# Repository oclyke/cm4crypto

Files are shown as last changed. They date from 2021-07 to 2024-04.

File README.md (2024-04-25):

# cm4crypto

cm4crypto is an adapter board that allows you to use an M-Key M.2 compatible module with the Raspberry Pi Compute Module 4 (cm4).

adding fast terabyte SSD options within a sleek RPi 4 format makes the cm4crypto perfect for uses like:
* participating in blockchain networks
* acting as a home media server
* hosting a local database

## status

this project is no longer actively developed.
the source material will continue to be available for reference.

additional resources:

* [onshape model](https://cad.onshape.com/documents/3095ac02ee5d7dd8a1b9e12a/w/86bdcc88d4120b9515956abd/e/6d8a025f4a8b2a44825a6443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)
* [time lapse of routing the board](https://youtu.be/ZWktmO8pLDk)

## features

* Adds M.2 M-Key PCIe x1 interface for use with NVMe SSDs or other compatible modules
* Designed for use in the [Flirc RPi 4 case](https://flirc.tv/more/raspberry-pi-4-case)
* Power Over Ethernet (PoE) support
* Camera Interface

# M.2 compatibility

M.2 specifies a connector layout, standard interfaces, and a few form factors. with such a wide variety of options available no single product can hope to support them all. here are the things you should check to see if your desired module is compatible:

property | value | notes
--- | ------- | ------
key | **M** | the M.2 connector on the cm4crypto uses an **M key**
interface | **PCIe x1** | though the M key standard supports PCIe x4 the cm4 only has x1 PCIe lane available. thanks to PCIe compatibility this should only reduce performance, not prevent functionality
dimensions | up to **22 x 80** mm | to fit in the case 

## RPi 4 compatibility

the cm4rypto inherently gains some compatibility with RPi 4 accessories since it was designed to work with the sleek Flirc case however design tradeoffs had to be made as well. 

### compatible

* 1x Gigabit ethernet
* 2x micro HDMI ports
* 1x USB-C port for power or USB OTG
* 1x USB-A port (USB 2.0)

### discrepancies

* there is **no 3.5mm audio jack**
* **GPIO is very limited** - only GPIO 2, 3, and 14 are available along with the first set of power pins (for PoE compatibility)
* the **camera interface is relocated** so that it comes out near the sd card
* the **sd card receptacle is slightly offset** to allow for the M.2 connector

## compatible / recommended products

### cases
* [Flirc Raspberry Pi 4 Case](https://flirc.tv/more/raspberry-pi-4-case)

### PoE hats
* [CMC Tech 3.5A](https://cctvfactory.com/copy-of-cmc-tech-5-2v-3-5a-17-5watt-power-over-ethernet-poe-hat-for-raspberry-pi-4-model-b-and-pi-3-model-b-ieee-802-3af-or-802-3at-poe-netwo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) (available on Amazon)
* 

# show and tell

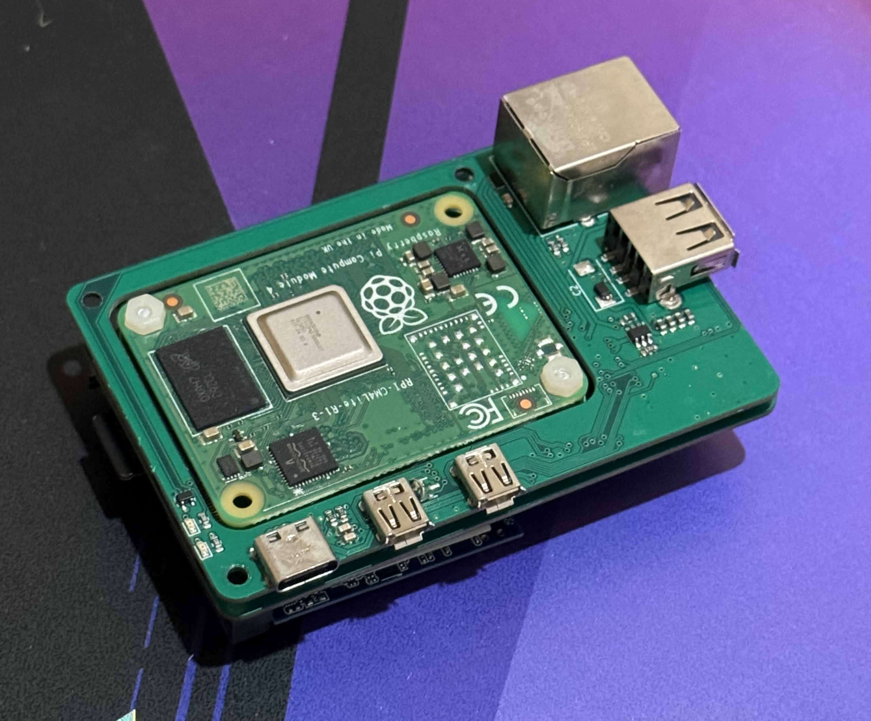
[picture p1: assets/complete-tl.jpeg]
cm4crypto


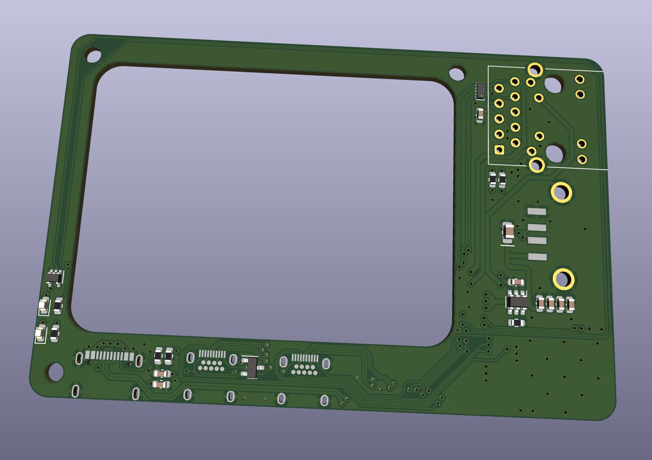
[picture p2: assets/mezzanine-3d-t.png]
mezzanine 3d top

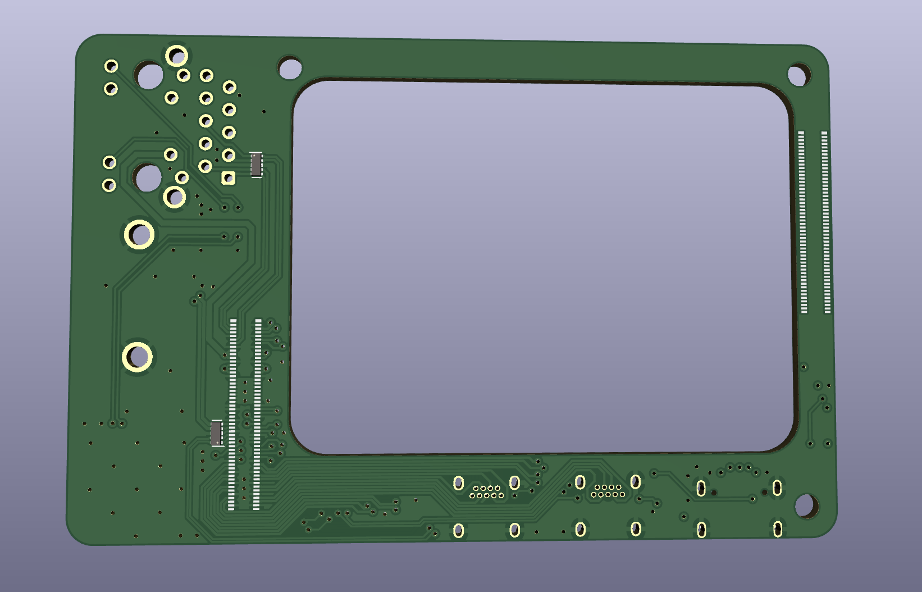
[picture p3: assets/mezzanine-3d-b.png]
mezzanine 3d bottom

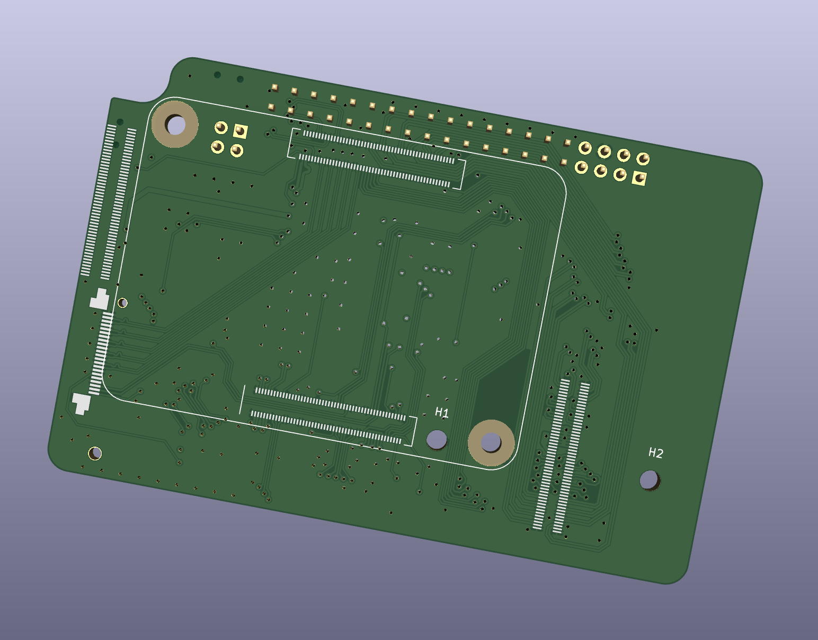
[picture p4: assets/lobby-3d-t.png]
lobby 3d top

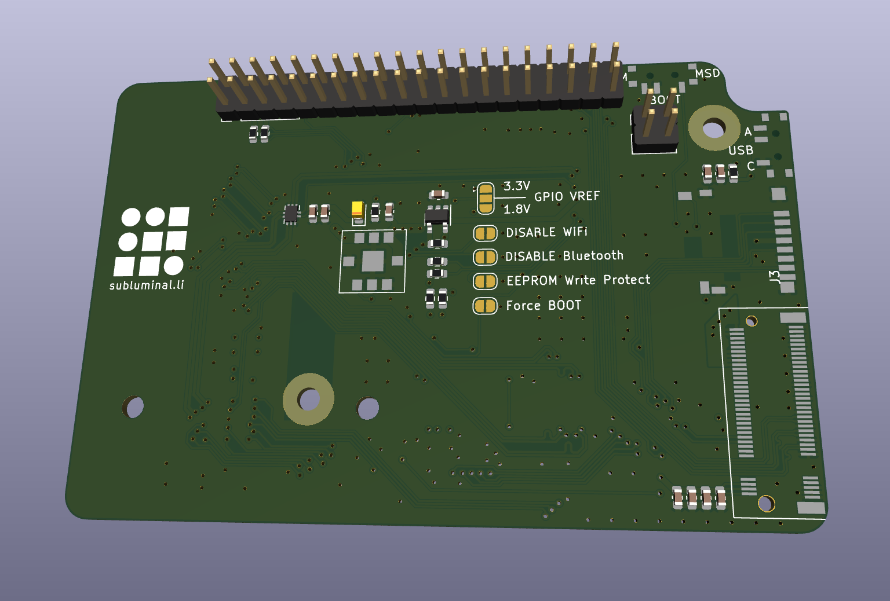
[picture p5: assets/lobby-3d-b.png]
lobby 3d bottom

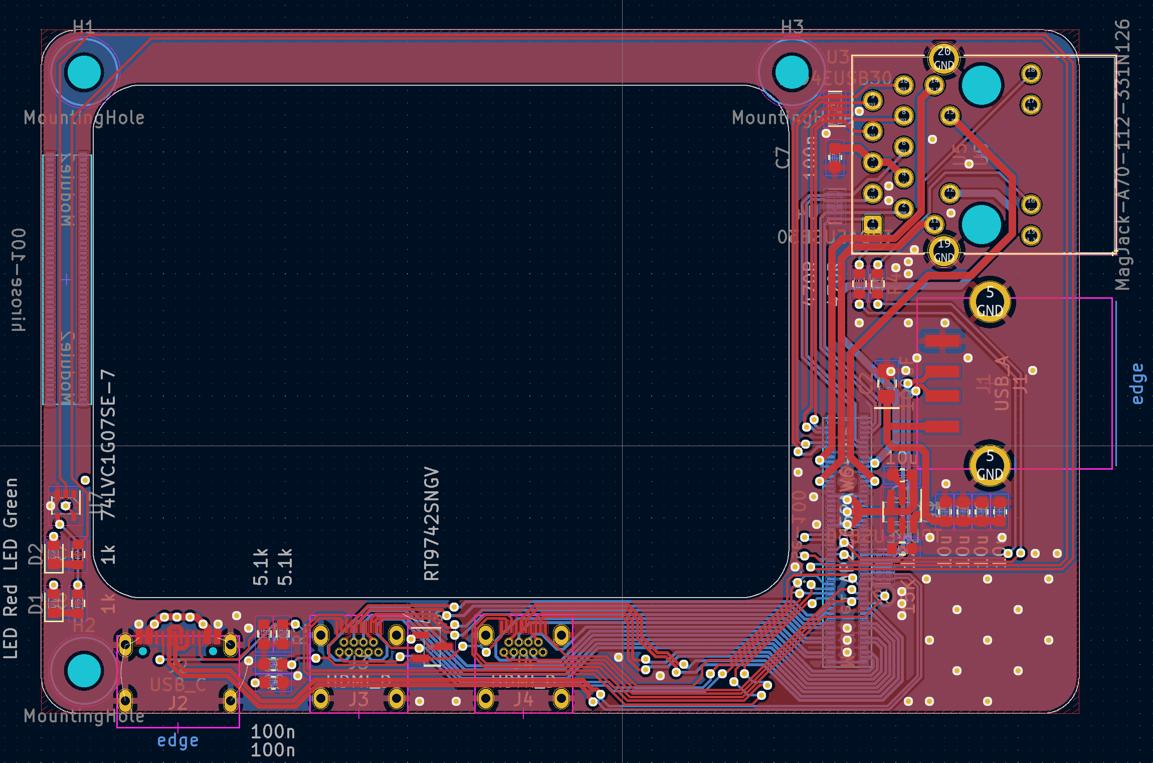
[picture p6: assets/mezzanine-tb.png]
mezzanine combined

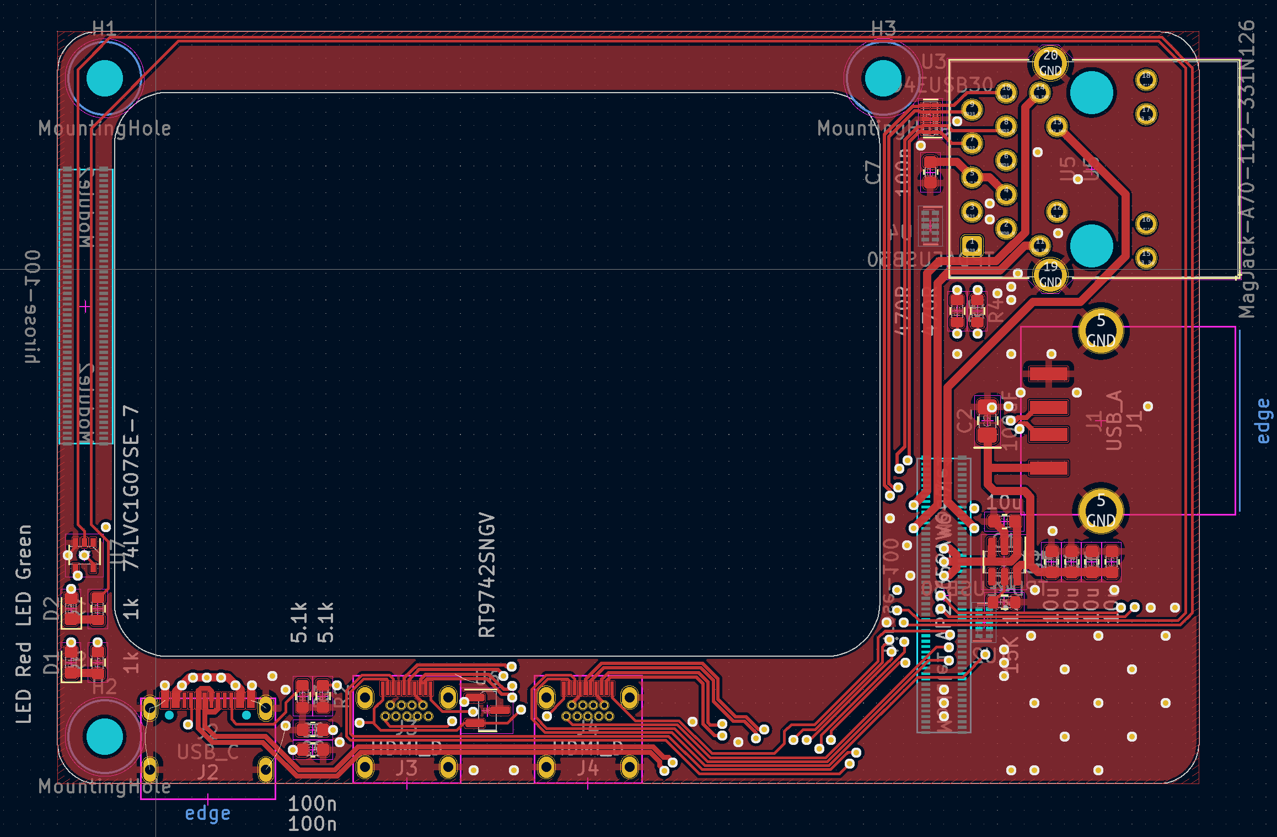
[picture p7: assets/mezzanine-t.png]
mezzanine top

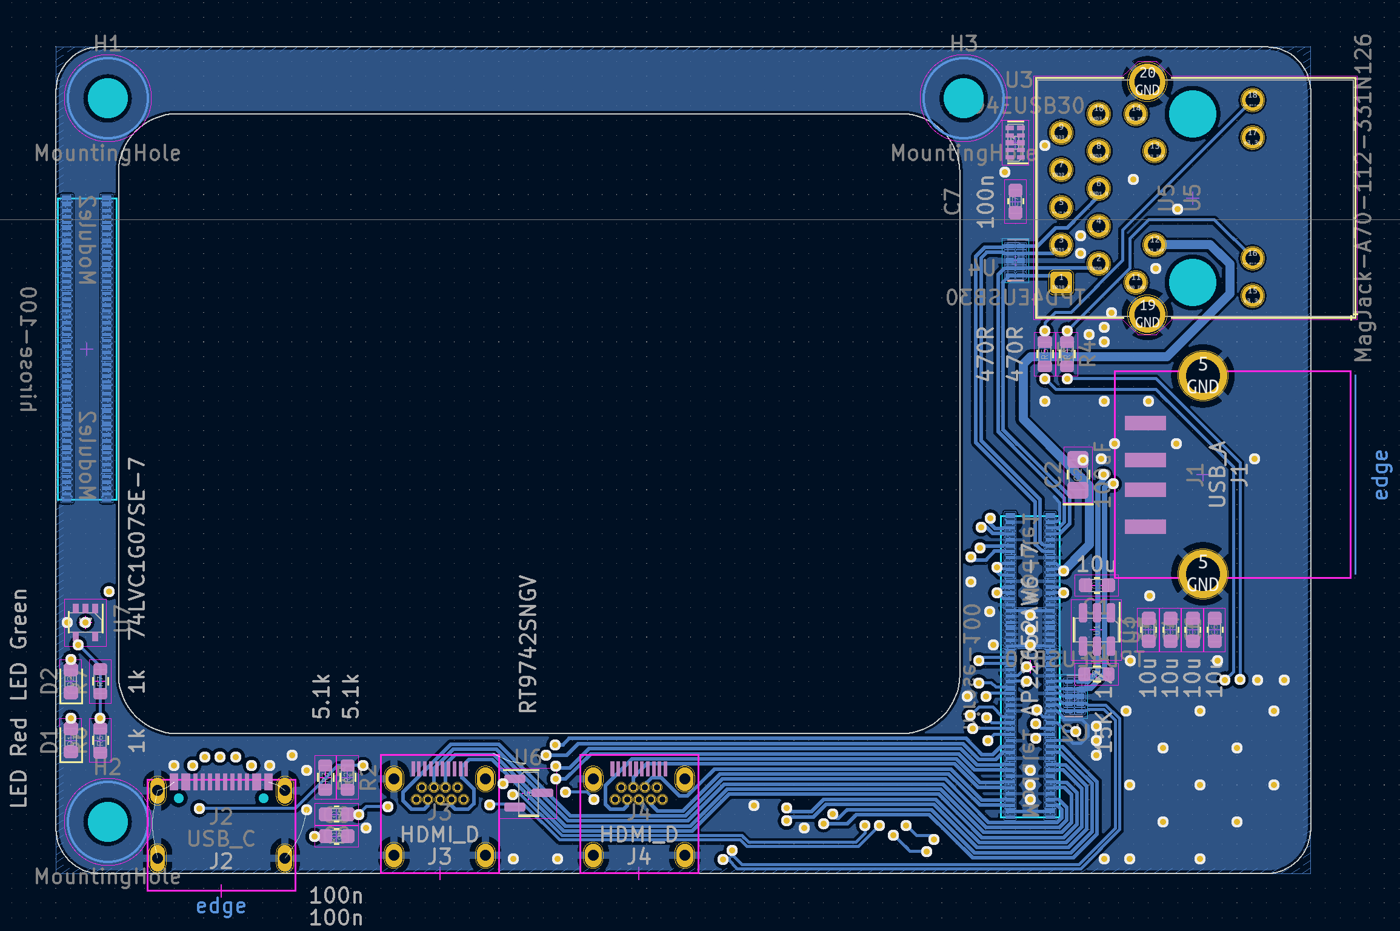
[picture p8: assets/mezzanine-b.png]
mezzanine bottom

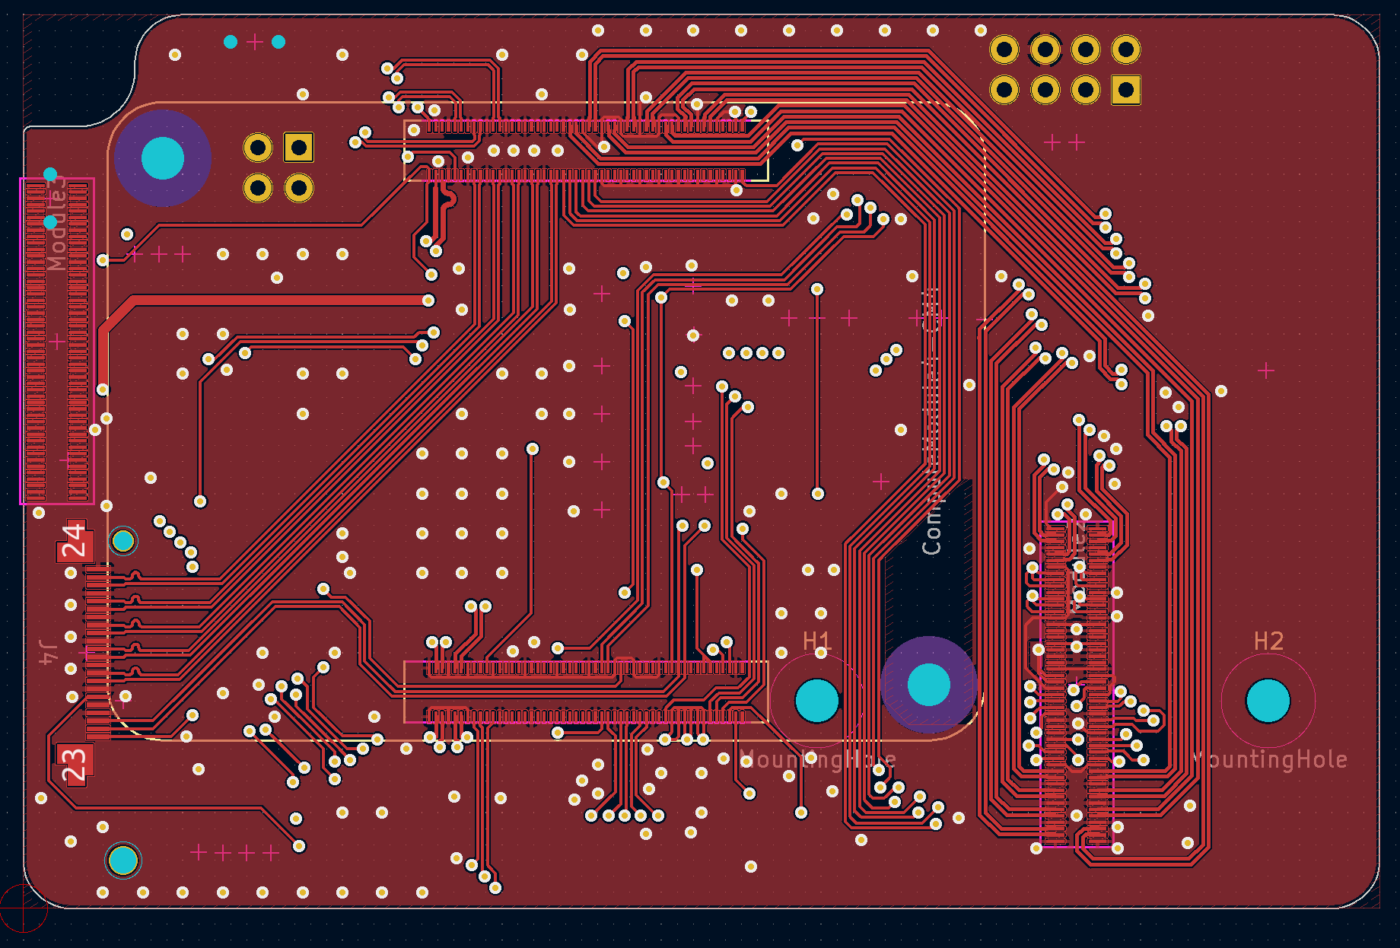
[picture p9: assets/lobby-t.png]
lobby top

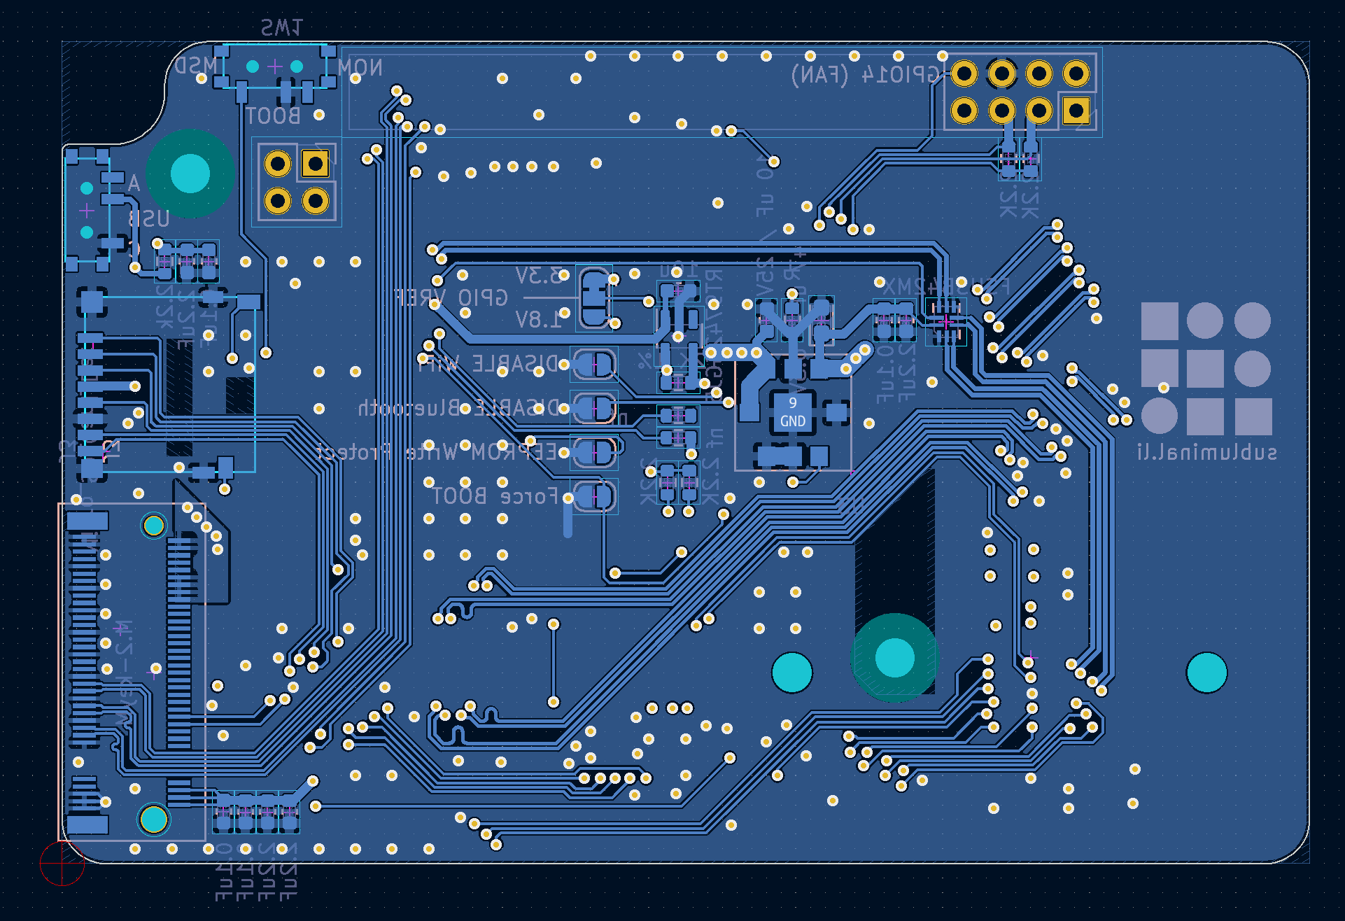
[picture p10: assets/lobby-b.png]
lobby bottom


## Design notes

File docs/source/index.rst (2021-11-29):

.. cm4crypto documentation main file:

cm4crypto
=========

cm4crypto is an adapter that packs a Raspberry Pi Compute Module 4, 
an M.2 connector for NVMe SSDs, and Power over Ethernet capability 
into the sleek Flirc RPi 4 case.

.. toctree::
   :maxdepth: 2

   start/index.rst
   compatibility/index.rst

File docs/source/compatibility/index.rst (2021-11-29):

Compatibility
=============

M.2 NVMe SSDs
*************

The M.2 M-key NVMe standard ensures that a wide array of SSDs will be compatible with 
cm4crypto.

The following devices have been tested successfully:

* `Sabrent Rocket 1TB <https://www.sabrent.com/product/SB-1342-1TB/1tb-rocket-nvme-pcie-m-2-2242-dram-less-low-power-internal-high-performance-ssd/>`_
* `WD_BLACK SN750 1TB <https://shop.westerndigital.com/products/internal-drives/wd-black-sn750-nvme-ssd#WDS100T3X0C>`_

Power Over Ethernet (PoE)
*************************

HATS
----

The additional power requirements of an NVMe drive may preclude most PoE options on the 
market designed for the Raspberry Pi 4. Below are some options that provide extra oomph...

* `CMC Tech 3.5A PoE HAT <https://smile.amazon.com/CMC-TECH-17-5Watt-Raspberry-Compliant/dp/B081C1TW3C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>`_

Switches
--------

Cameras
*******

cm4crypto uses the same camera connector and interface as the Raspberry Pi Zero.
Most 22-pin cameras designed for the Raspberry Pi should work out of the box.

The following products are known to work:

* `MakeFocus Raspberry Pi 4 Camera <https://smile.amazon.com/gp/product/B075149PWB/ref=ppx_yo_dt_b_asin_title_o08_s00?ie=UTF8&psc=1>`_

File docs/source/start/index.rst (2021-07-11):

Getting Started
===============

How to get up and running with the cm4crypto adaptor

Prerequisites
*************

You will need:

* Raspberry Pi Compute Module 4
   * you may choose the appropriate model for your needs depending on size of RAM, 
     type/amount of storage, and WiFi support
* cm4crypto adapter kit
* power supply
   * USB-C cable or PoE
* firmware flashing method
   * SD card *OR* USB-C cable for modules with EMMC storage

Assembly
********
.. include:: assembly.rst

Setup
*****
.. include:: setup.rst

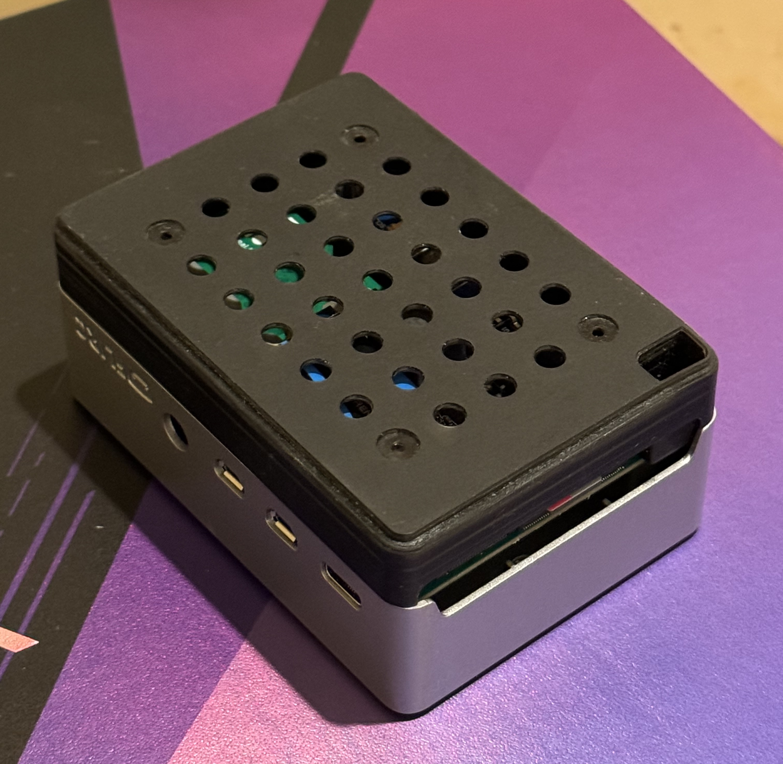
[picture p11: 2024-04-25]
assets/complete-2.jpeg

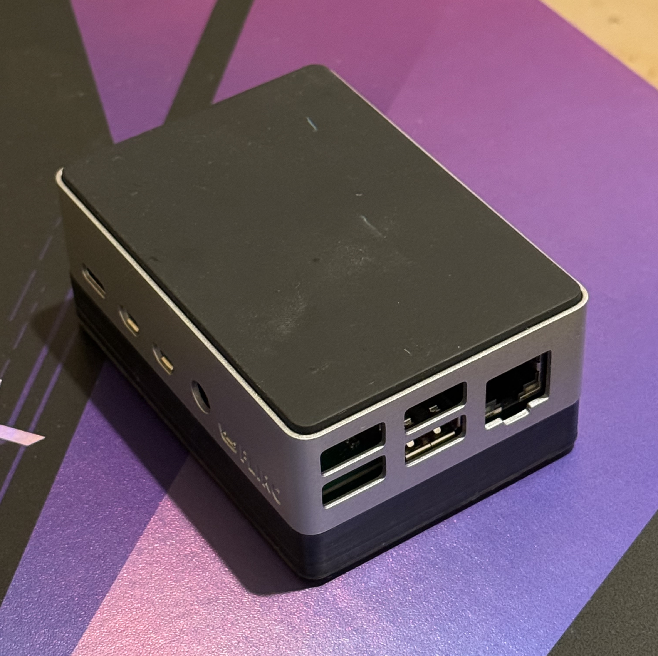
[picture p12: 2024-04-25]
assets/complete-1.jpeg

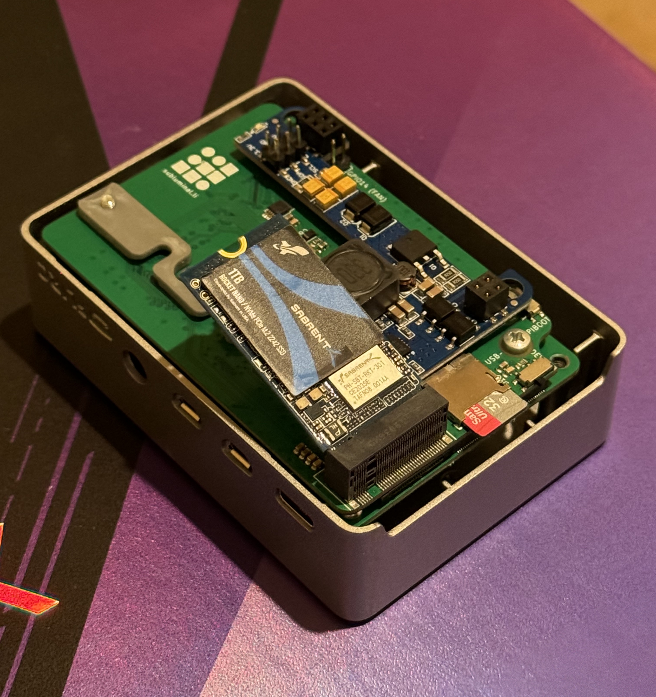
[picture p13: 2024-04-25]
assets/complete-3.jpeg

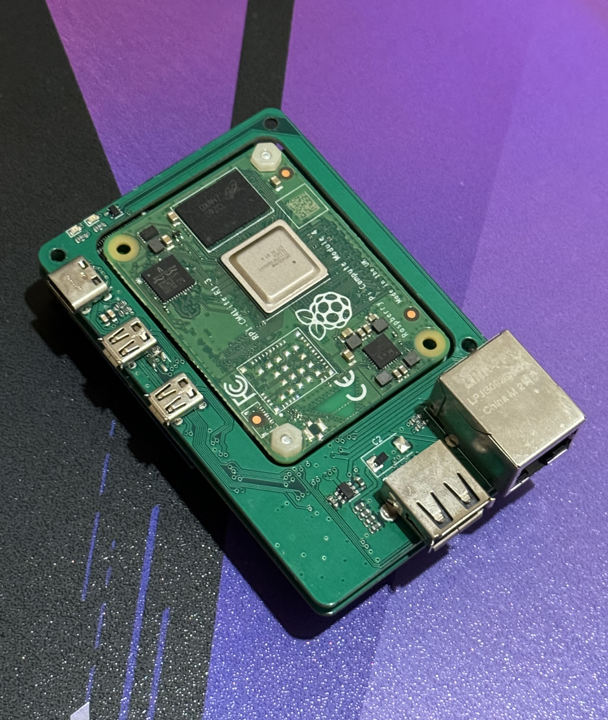
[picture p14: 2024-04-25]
assets/complete-tr.jpeg

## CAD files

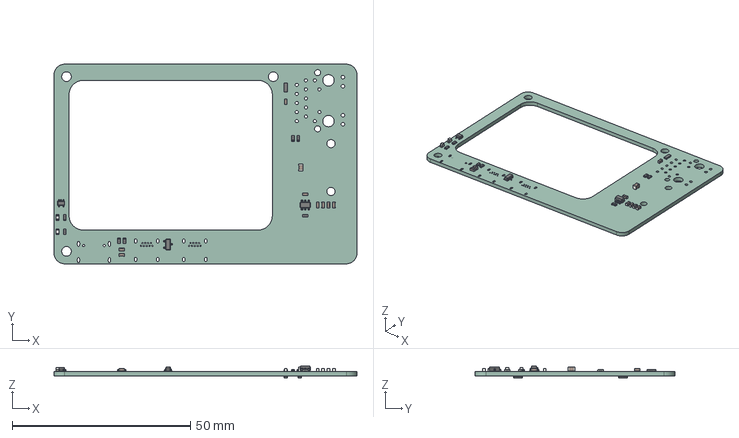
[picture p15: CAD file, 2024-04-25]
hardware/mezzanine/mezzanine.step
85.0 x 56.0 x 3.50 mm
mezzanine PCB

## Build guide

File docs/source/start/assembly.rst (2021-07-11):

cm4crypto gets assembled with ease. You just need to:

* connect a Raspberry Pi Compute Module 4 to the lobby board
* connect the mezzanine board to the lobby board

You may also choose to install additional hardware like:

* install into a Flirc case
* add an NVMe solid state drive
* add a Power Over Ethernet HAT

Here's how to do each part in order.

install PoE HAT
---------------

* align the PoE HAT over the male pins as shown
* press firmly until PoE HAT is seated

installation of PoE HAT

install M.2 NVMe SSD module
---------------------------

* insert the module to the connector at a 30 degree angle, ensuring it is fully inserted

   * hook the adaptor onto the standoff hole on the module

      * for 2280 modules use the adaptor w/o a dogbone inserted
      * for 2260 or 2242 modules place a dogbone in the corresponding slot
      
   * from the top side of the lobby (lower) board use two 5mm length screws to affix the adapter

insert the module to the connector

installing adaptor

install Compute Module 4 (cm4)
------------------------------

* make sure the outline of the module lines up with the outline drawn on the lobby board
* press firmly above each of the two connectors until you hear and feel a click
* use spacers, nuts, and 8mm screws to affix the module to the board

aligning compute module on lobby board

firmly pressing module into connectors

install a Flirc case
--------------------

.. note:: The mezzanine board must be attached to the Flirc case *before* the lobby board is attached

* insert the mezzanine board into the case
* use three screws from the Flirc case to attach the board

.. note:: Using all three screw holes is important to make the connection between the lobby and mezzanine
  boards easier.

mezzanine board installed in case

mate the lobby and mezzanine boards
-----------------------------------

* align the top and bottom boards 
* press firmly above each of the two connectors until you hear and feel a click

connection of lobby and mezzanine boards

lobby and mezzanine boards connected

install bottom tray
-------------------

* remove one screw from the corner of the mezzanine board

  * this is the only screw that is accessible

* place the tray over the case and pcb stack
* replace the screw in the corner through the bottom tray

corner screw removal

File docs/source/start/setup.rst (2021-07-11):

Setup of the cm4crypto is very similar to setup of a typical raspberry pi computer. 

flashing an operating system
----------------------------

Most of the time standard Raspberry Pi boards use the SD card to store the operating system (OS). 
When using the Compute Module 4 (cm4) you will either store the OS on an SD card or on internal eMMC
memory, depending on the options you've selected when you purchased the module.

.. note::
   Compute modules with eMMC storage **cannot** boot from the SD card. 
   Check this Raspberry Pi forum post for more detail: 
   `Can CM4 with eMMC boot from SD card <https://www.raspberrypi.org/forums/viewtopic.php?t=305506>`_

eMMC
^^^^

The eMMC memory module will act a lot like an SD card would when setting up a normal Raspberry Pi except
you can't simply take it out and put it in your computer. Instead the Compute Module needs to be put
into *bootloader* mode which will mount the eMMC on your computer as a USB mass storage device. Then it
can be used just like a normal RPi SD card.

To mount the eMMC as USB mass storage device:

* download `raspberrypi/usbboot <https://github.com/raspberrypi/usbboot>`_

* turn the **BOOT** switch on cm4crypto to ``MSD``
* turn the **USB** switch on cm4crypto ``C``
* plug in cm4crypto to your computer via the USB-C port
   * the Compute Module should turn on in boot mode awaiting the next steps

The next step depends on your computer's operating system

.. note:: *Windows*

   * use **rpiboot_setup.exe** to install required drivers and boot tool
   * start **rpiboot.exe**

.. note:: *Linux / OSX*

   * install libusb

      * Linux: ``apt install -y libusb-1.0.0-dev``
      * OSX: ``brew install libusb``
      
   * build the executable in the ``raspberrypi/usbboot`` root directory ``make``
   * run the rpiboot executable ``./rpiboot``

* now the Compute Module should appear on your computer as a removable drive called ``boot``
* proceed to flash your desired operating system on this drive using your preferred tool

   * `Raspberry Pi Imager <https://www.raspberrypi.org/software/>`_
   * `Balena Etcher <https://www.balena.io/etcher/>`_

.. note:: Initially your computer may give you an error like 

   ``the disk you inserted was not able to be read by the system``

   this is because the disk is not formatted and will not affect the image writing tool's 
   ability to flash the OS

* once the image is flashed you may choose to do optional configuration or skip straight to the first boot.

Jeff Geerling made an excellent video about the process which you can see here:

.. raw:: html
   
   <iframe
      width="100%"
      height="475"
      src="https://www.youtube.com/embed/jp_mF1RknU4"
      title="YouTube video player"
      frameborder="0"
      allow="accelerometer; autoplay; clipboard-write; encrypted-media; gyroscope; picture-in-picture"
      allowfullscreen>
   </iframe>

SD
^^

* insert an SD card in your computer

   * it should appear as a removable storage device

* flash your desired operating system on this drive using your preferred tool

   * `Raspberry Pi Imager <https://www.raspberrypi.org/software/>`_
   * `Balena Etcher <https://www.balena.io/etcher/>`_

* once the image is flashed you may choose to do optional configuration or skip straight to the first boot

optional configuration
----------------------

Once you have flashed the OS to your Compute Module you may perform some initial configuration by modifying 
files on the eMMC boot drive / SD card. This is especially useful for configuring a headless machine.

enable USB2.0 host controller
^^^^^^^^^^^^^^^^^^^^^^^^^^^^^

Unlike the Raspberry Pi the Compute Module 4 leaves its USB2.0 host controller disabled by default to save power. 
In order to use the USB-A port on the cm4crypto you must add the following line to the **boot/config.txt** file. 
If you choose not to do this now it will still be possible by editing **/boot/config.txt** while the Pi is running. 
Changes will take effect on the next boot up.

``dtoverlay=dwc2,dr_mode=host``

enabling ssh
^^^^^^^^^^^^

SSH can be used control the Pi remotely, relying on the display and keyboard of another computer, but it is
disabled by default. To enable it you must simply add a file called **ssh** in the boot directory. (The root of the removable storage device)

enable wifi
^^^^^^^^^^^

* add **wpa_supplicant.conf** in the boot partition (**/boot**)

   * [raspberry pi foundation documentation](https://www.raspberrypi.org/documentation/configuration/wireless/headless.md)
   * [stack overflow multiple network config](https://raspberrypi.stackexchange.com/questions/11631/how-to-setup-multiple-wifi-networks)

**example**
::

   ctrl_interface=DIR=/var/run/wpa_supplicant GROUP=netdev
   country=<Insert 2 letter ISO 3166-1 country code here>
   update_config=1

   network={
      ssid="<name of your wireless LAN>"
      psk="<password for your wireless LAN>"
      id_str="<identifier for your wireless LAN>"
   }

   network={
      ssid="<name of another wireless LAN>"
      psk="<password for the other wireless LAN>"
      id_str="<identifier for the other wireless LAN>"
   }

enable camera interface
^^^^^^^^^^^^^^^^^^^^^^^

The Compute Module also ships without support for the camera interface enabled. To get the camera working
you need to add a device tree configuration blob to the root file system.

To generate the file yourself follow the `documentation <https://www.raspberrypi.org/documentation/hardware/computemodule/cmio-camera.md>`_

To get started faster you can use the generic file ``dt-blob.bin`` in the ``device-tree`` directory of the `cm4crypto repository <https://github.com/subluminal-li/cm4crypto>`_

change the pi user's password
^^^^^^^^^^^^^^^^^^^^^^^^^^^^^

The default password for the ``pi`` user is insecure (it is all over the internet!). There are several 
strategies for mending this security concern without exposing your computer to the public internet for
any duration unprotected.

Get started with `this thread <https://www.raspberrypi.org/forums/viewtopic.php?t=289155>`_

first boot
----------

* remove power from the board
* ensure that the **BOOT** switch is in the ``NOM`` position

   * remember - if you want to use the USB-A host port ensure the **USB** switch is in the ``A`` position

* plug in any peripherals you want to use (HDMI, USB, etc)
* apply power

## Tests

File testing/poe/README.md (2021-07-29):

# poe test

## setup
symlink the ```korad``` module into the poe testing directory

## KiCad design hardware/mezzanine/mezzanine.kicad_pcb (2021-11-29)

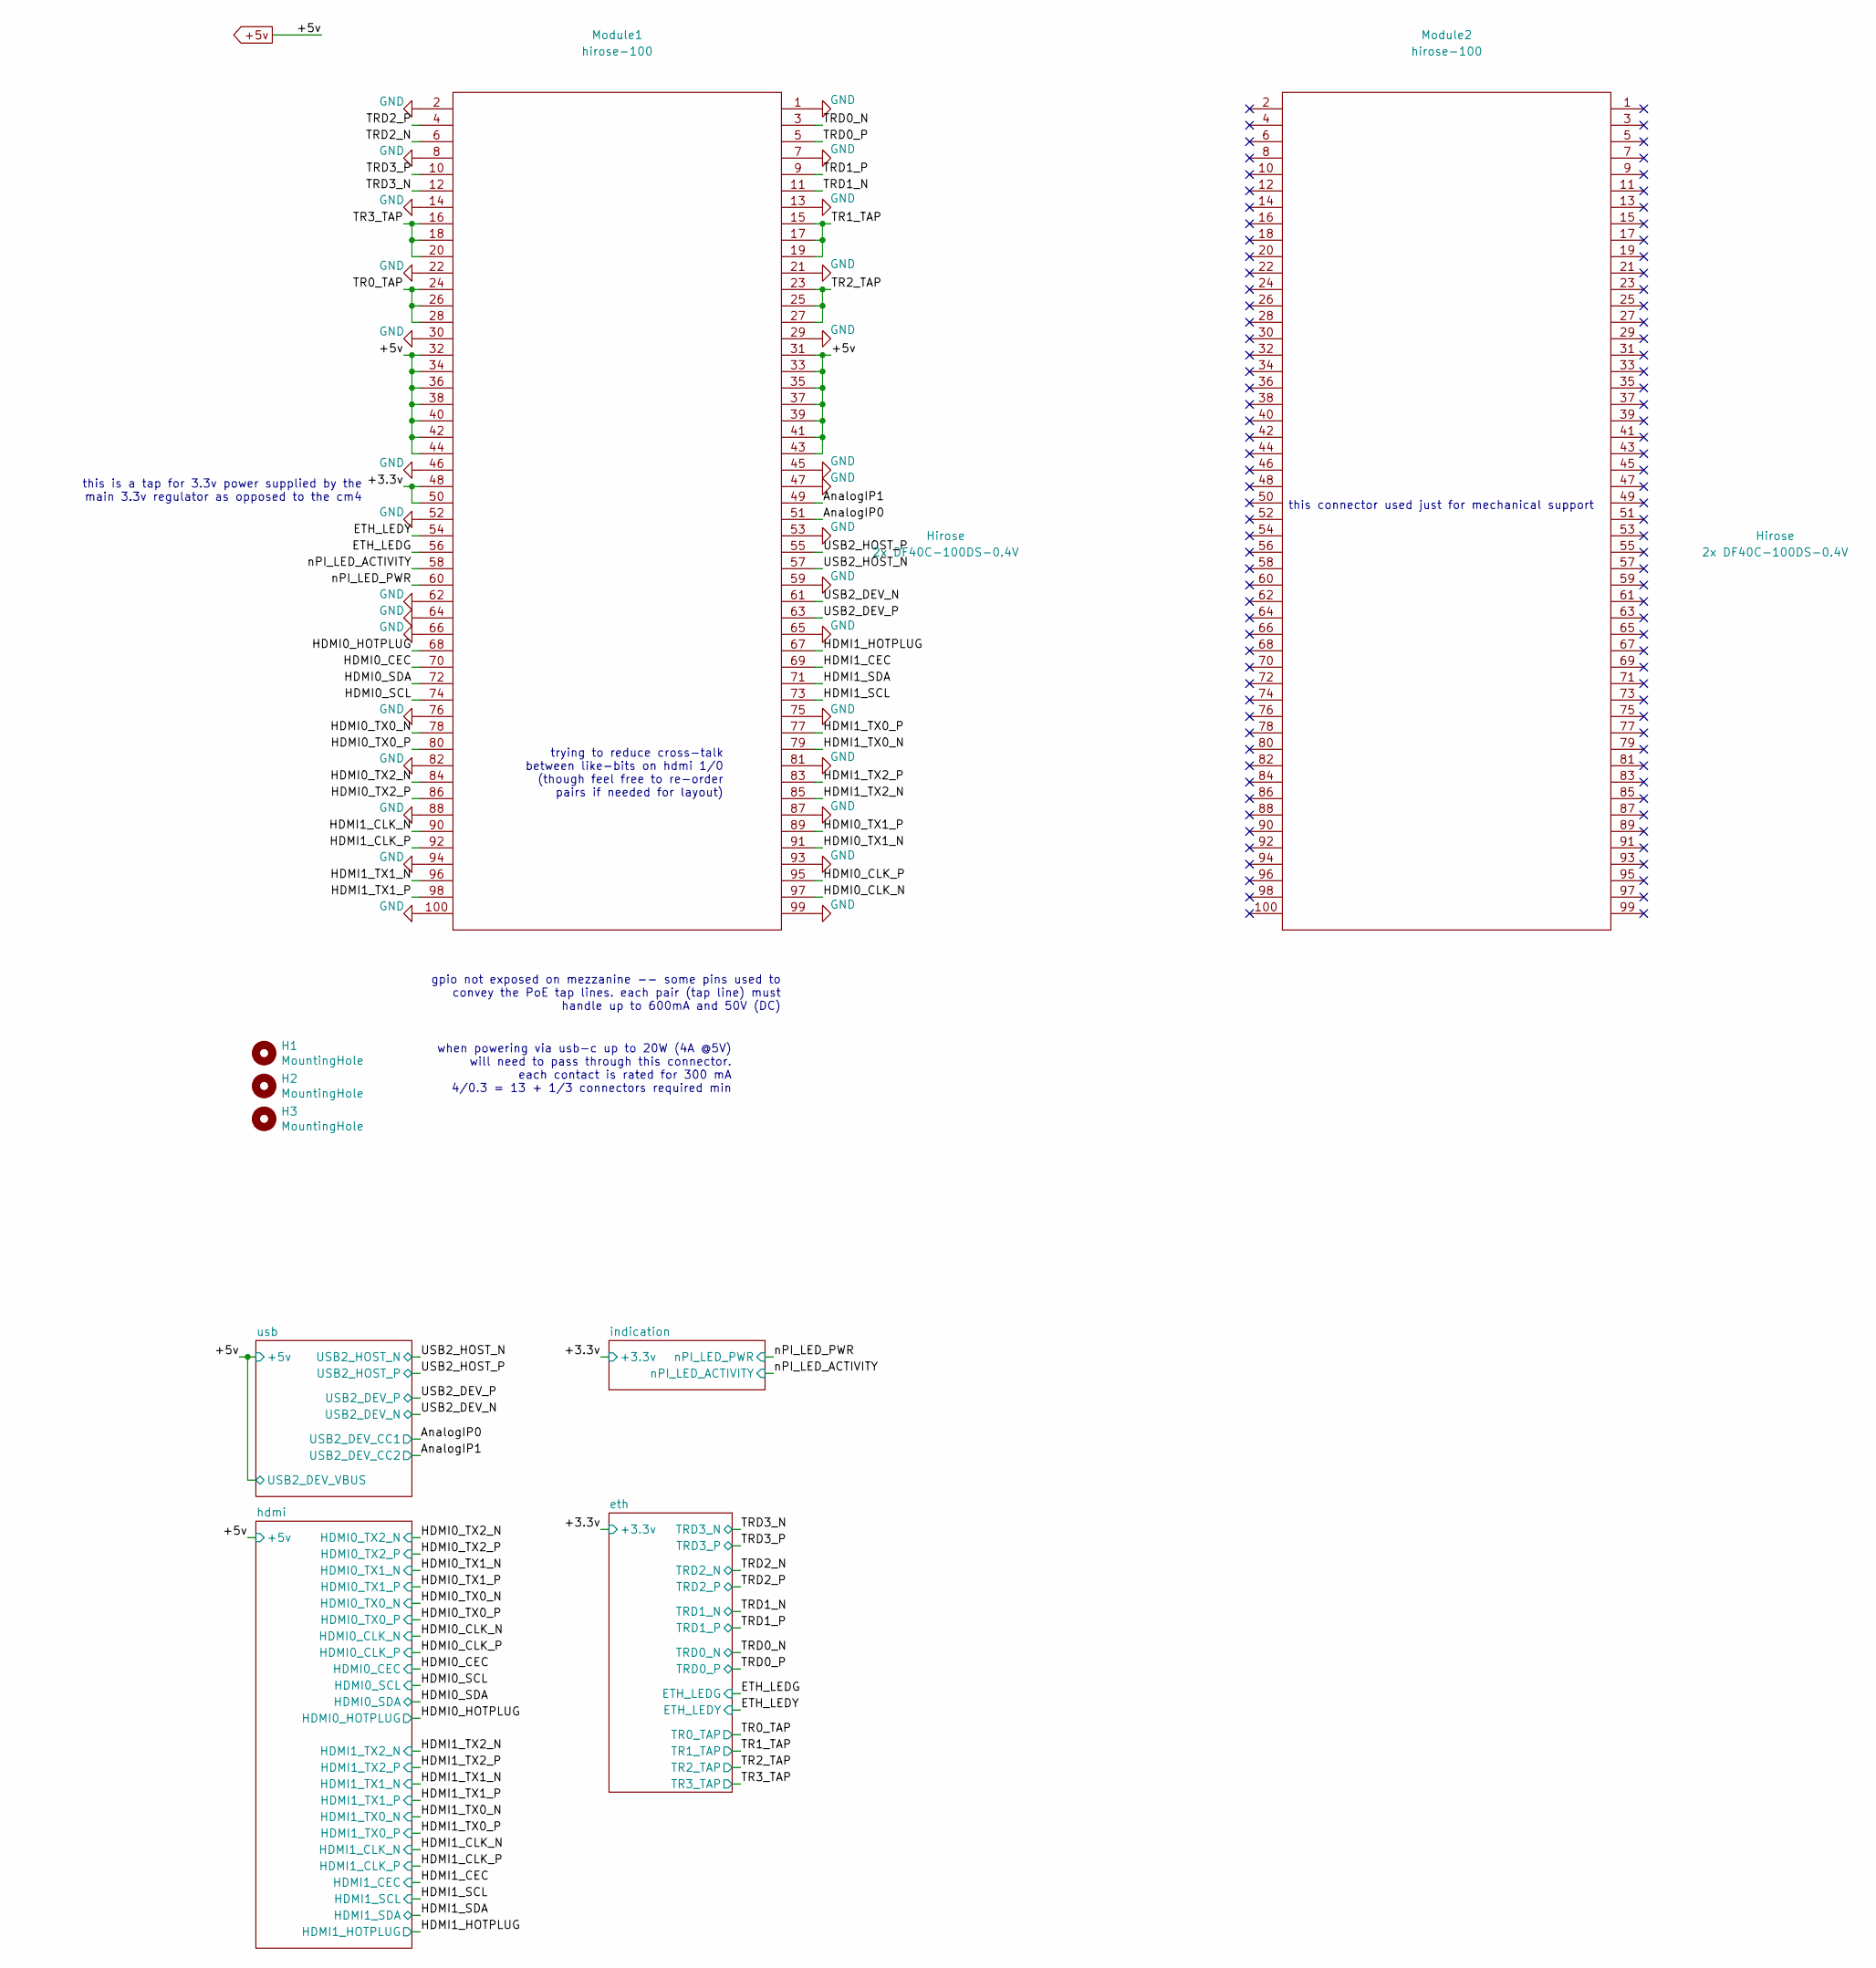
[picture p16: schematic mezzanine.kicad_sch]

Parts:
H1, H2, H3: MountingHole; MountingHole_2.7mm_M2.5
Module1, Module2: hirose-100; DF40C-100DP-0.4V(51)

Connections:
+5v: Module1.31, Module1.32, Module1.33, Module1.34, Module1.35, Module1.36, Module1.37, Module1.38, Module1.39, Module1.40, Module1.41, Module1.42, Module1.43, Module1.44; also elsewhere on the board
/+3.3v: Module1.48, Module1.50; also elsewhere on the board
/AnalogIP0: Module1.51
/AnalogIP1: Module1.49
/ETH_LEDG: Module1.56; also elsewhere on the board
/ETH_LEDY: Module1.54; also elsewhere on the board
/HDMI0_CEC: Module1.70; also elsewhere on the board
/HDMI0_CLK_N: Module1.97; also elsewhere on the board
/HDMI0_CLK_P: Module1.95; also elsewhere on the board
/HDMI0_HOTPLUG: Module1.68; also elsewhere on the board
/HDMI0_SCL: Module1.74; also elsewhere on the board
/HDMI0_SDA: Module1.72; also elsewhere on the board
/HDMI0_TX0_N: Module1.78; also elsewhere on the board
/HDMI0_TX0_P: Module1.80; also elsewhere on the board
/HDMI0_TX1_N: Module1.91; also elsewhere on the board
/HDMI0_TX1_P: Module1.89; also elsewhere on the board
/HDMI0_TX2_N: Module1.84; also elsewhere on the board
/HDMI0_TX2_P: Module1.86; also elsewhere on the board
/HDMI1_CEC: Module1.69; also elsewhere on the board
/HDMI1_CLK_N: Module1.90; also elsewhere on the board
/HDMI1_CLK_P: Module1.92; also elsewhere on the board
/HDMI1_HOTPLUG: Module1.67; also elsewhere on the board
/HDMI1_SCL: Module1.73; also elsewhere on the board
/HDMI1_SDA: Module1.71; also elsewhere on the board
/HDMI1_TX0_N: Module1.79; also elsewhere on the board
/HDMI1_TX0_P: Module1.77; also elsewhere on the board
/HDMI1_TX1_N: Module1.96; also elsewhere on the board
/HDMI1_TX1_P: Module1.98; also elsewhere on the board
/HDMI1_TX2_N: Module1.85; also elsewhere on the board
/HDMI1_TX2_P: Module1.83; also elsewhere on the board
/TR0_TAP: Module1.24, Module1.26, Module1.28; also elsewhere on the board
/TR1_TAP: Module1.15, Module1.17, Module1.19; also elsewhere on the board
/TR2_TAP: Module1.23, Module1.25, Module1.27; also elsewhere on the board
/TR3_TAP: Module1.16, Module1.18, Module1.20; also elsewhere on the board
/TRD0_N: Module1.3; also elsewhere on the board
/TRD0_P: Module1.5; also elsewhere on the board
/TRD1_N: Module1.11; also elsewhere on the board
/TRD1_P: Module1.9; also elsewhere on the board
/TRD2_N: Module1.6; also elsewhere on the board
/TRD2_P: Module1.4; also elsewhere on the board
/TRD3_N: Module1.12; also elsewhere on the board
/TRD3_P: Module1.10; also elsewhere on the board
/USB2_DEV_N: Module1.61; also elsewhere on the board
/USB2_DEV_P: Module1.63; also elsewhere on the board
/USB2_HOST_N: Module1.57; also elsewhere on the board
/USB2_HOST_P: Module1.55; also elsewhere on the board
/nPI_LED_ACTIVITY: Module1.58; also elsewhere on the board
/nPI_LED_PWR: Module1.60; also elsewhere on the board
GND: Module1.1, Module1.2, Module1.7, Module1.8, Module1.13, Module1.14, Module1.21, Module1.22, Module1.29, Module1.30, Module1.45, Module1.46, Module1.47, Module1.52, Module1.53, Module1.59, Module1.62, Module1.64, Module1.65, Module1.66, Module1.75, Module1.76, Module1.81, Module1.82, Module1.87, Module1.88, Module1.93, Module1.94, Module1.99, Module1.100; also elsewhere on the board

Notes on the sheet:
this is a tap for 3.3v power supplied by the main 3.3v regulator as opposed to the cm4
trying to reduce cross-talk between like-bits on hdmi 1/0 (though feel free to re-order pairs if needed for layout)
when powering via usb-c up to 20W (4A @5V) will need to pass through this connector. each contact is rated for 300 mA 4/0.3 = 13 + 1/3 connectors required min
gpio not exposed on mezzanine -- some pins used to convey the PoE tap lines. each pair (tap line) must handle up to 600mA and 50V (DC)
this connector used just for mechanical support

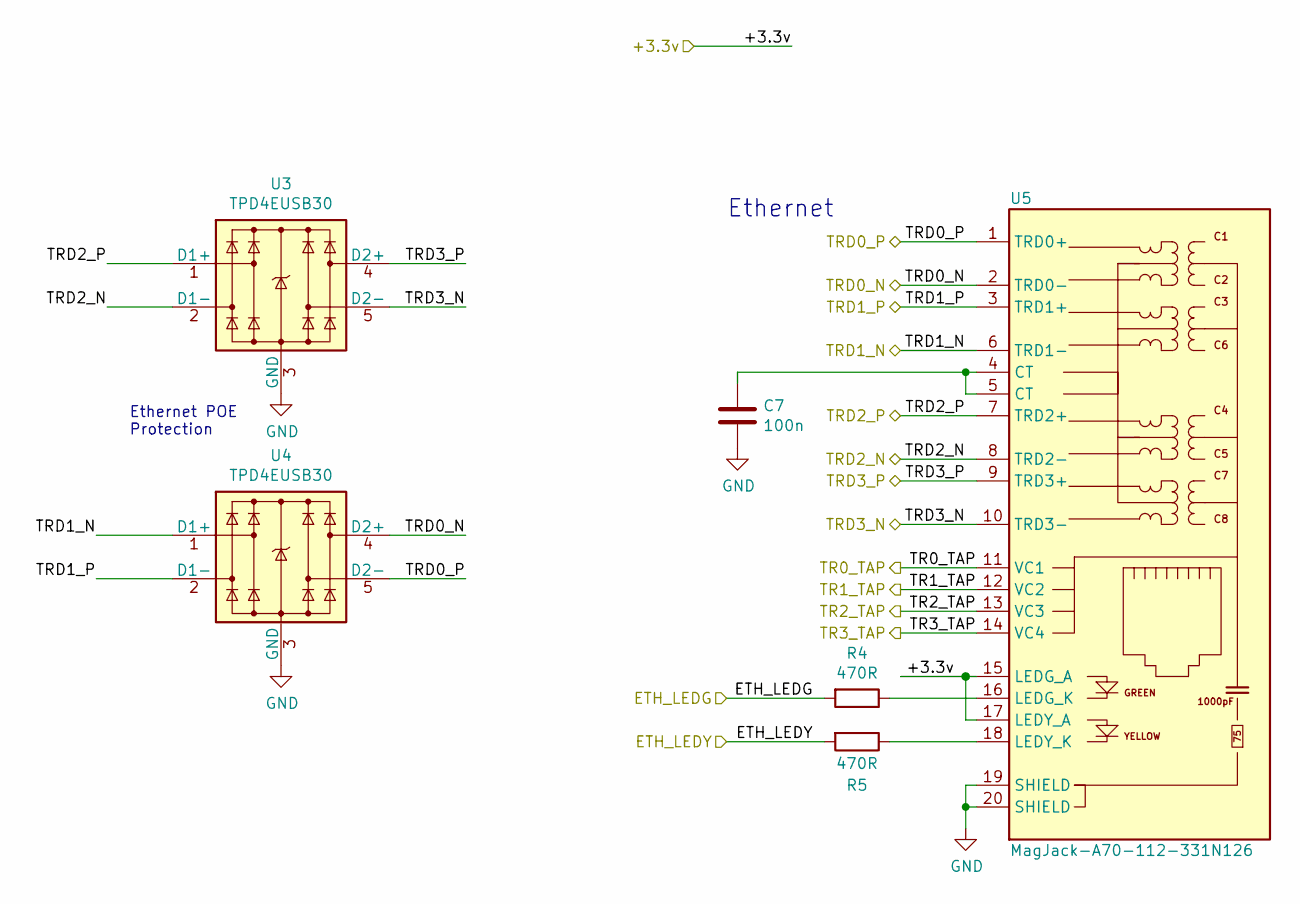
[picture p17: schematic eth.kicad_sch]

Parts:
C7: 100n; C_0603_1608Metric
R4, R5: 470R; R_0603_1608Metric
U3, U4: TPD4EUSB30; USON-10_2.5x1.0mm_P0.5mm; Part Description Quad TVS diode for high speed signals (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
U5: MagJack-A70-112-331N126; TRJG0926HENL; Part Description Gigabit Ethernet Magjack

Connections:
/+3.3v: U5.15 (LEDG_A), U5.17 (LEDY_A); also elsewhere on the board
/ETH_LEDG: R4.2; also elsewhere on the board
/ETH_LEDY: R5.2; also elsewhere on the board
/TR0_TAP: U5.11 (VC1); also elsewhere on the board
/TR1_TAP: U5.12 (VC2); also elsewhere on the board
/TR2_TAP: U5.13 (VC3); also elsewhere on the board
/TR3_TAP: U5.14 (VC4); also elsewhere on the board
/TRD0_N: U4.4 (D2+), U4.7, U5.2 (TRD0-); also elsewhere on the board
/TRD0_P: U4.5 (D2-), U4.6, U5.1 (TRD0+); also elsewhere on the board
/TRD1_N: U4.1 (D1+), U4.10, U5.6 (TRD1-); also elsewhere on the board
/TRD1_P: U4.2 (D1-), U4.9, U5.3 (TRD1+); also elsewhere on the board
/TRD2_N: U3.2 (D1-), U3.9, U5.8 (TRD2-); also elsewhere on the board
/TRD2_P: U3.1 (D1+), U3.10, U5.7 (TRD2+); also elsewhere on the board
/TRD3_N: U3.5 (D2-), U3.6, U5.10 (TRD3-); also elsewhere on the board
/TRD3_P: U3.4 (D2+), U3.7, U5.9 (TRD3+); also elsewhere on the board
GND: C7.2, U3.3 (GND), U3.8 (GND), U4.3 (GND), U4.8 (GND), U5.19 (SHIELD), U5.20 (SHIELD); also elsewhere on the board
unnamed: C7.1, U5.4 (CT), U5.5 (CT)
unnamed: R4.1, U5.16 (LEDG_K)
unnamed: R5.1, U5.18 (LEDY_K)

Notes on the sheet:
Ethernet POE Protection
Ethernet

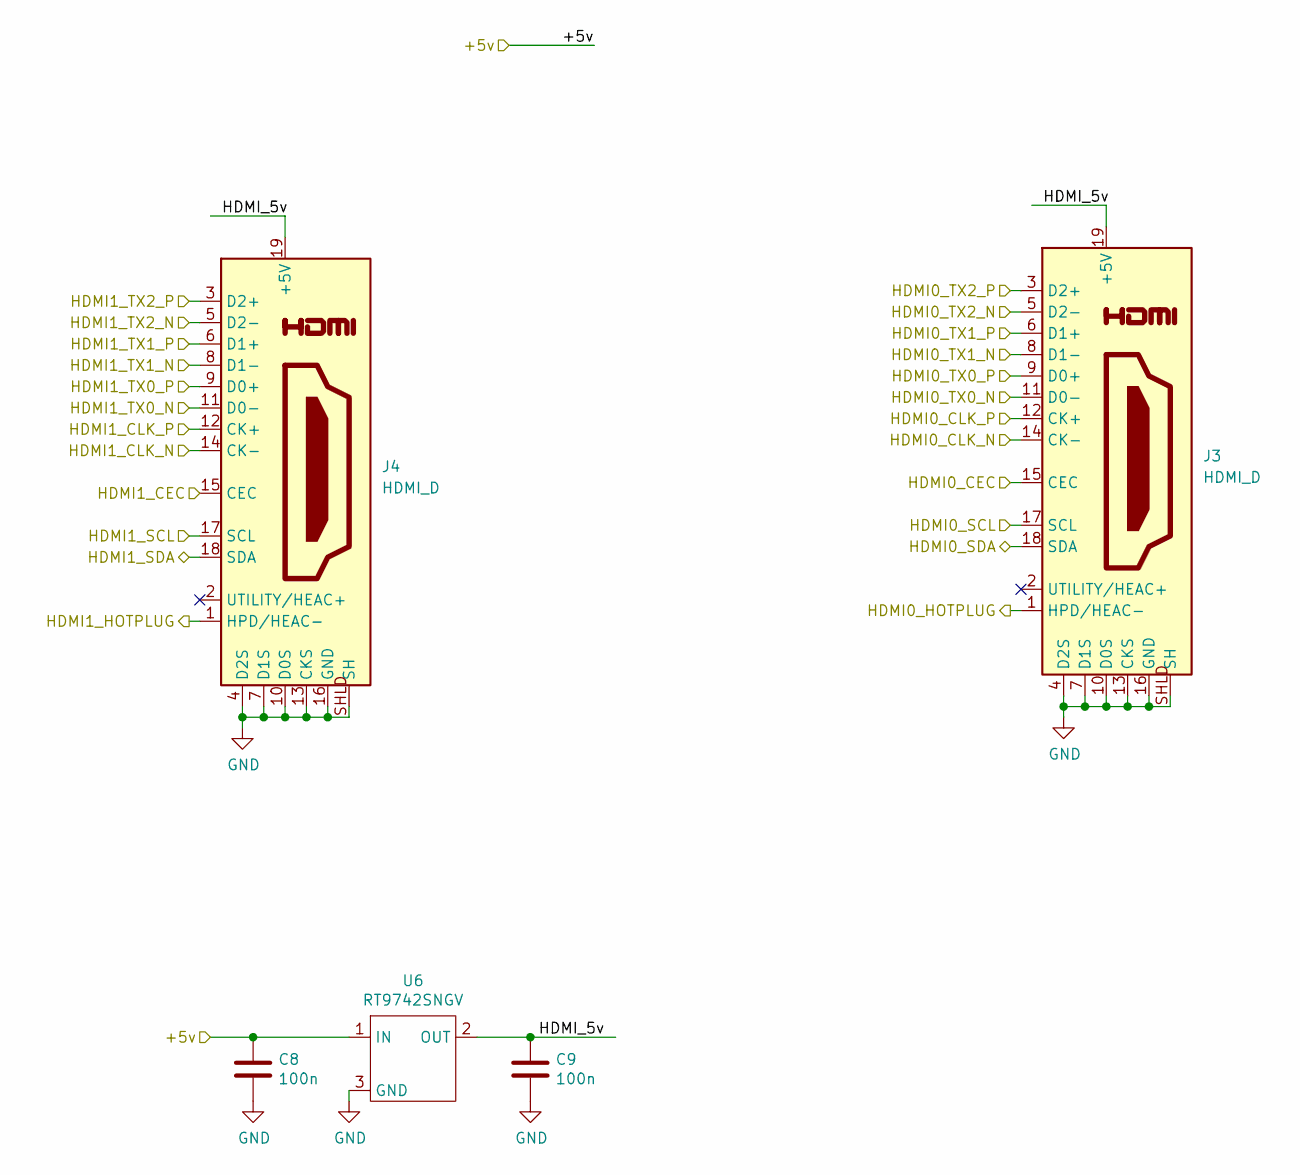
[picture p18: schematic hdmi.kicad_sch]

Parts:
C8, C9: 100n; C_0603_1608Metric
J3, J4: HDMI_D; HD-RA-DSF12-TR
U6: RT9742SNGV; SOT-23; Part Description Power Switch/Driver 1:1 N-Channel 500mA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

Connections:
+5v: C8.1, U6.1 (IN); also elsewhere on the board
/HDMI0_CEC: J3.15 (CEC); also elsewhere on the board
/HDMI0_CLK_N: J3.14 (CK-); also elsewhere on the board
/HDMI0_CLK_P: J3.12 (CK+); also elsewhere on the board
/HDMI0_HOTPLUG: J3.1 (HPD/HEAC-); also elsewhere on the board
/HDMI0_SCL: J3.17 (SCL); also elsewhere on the board
/HDMI0_SDA: J3.18 (SDA); also elsewhere on the board
/HDMI0_TX0_N: J3.11 (D0-); also elsewhere on the board
/HDMI0_TX0_P: J3.9 (D0+); also elsewhere on the board
/HDMI0_TX1_N: J3.8 (D1-); also elsewhere on the board
/HDMI0_TX1_P: J3.6 (D1+); also elsewhere on the board
/HDMI0_TX2_N: J3.5 (D2-); also elsewhere on the board
/HDMI0_TX2_P: J3.3 (D2+); also elsewhere on the board
/HDMI1_CEC: J4.15 (CEC); also elsewhere on the board
/HDMI1_CLK_N: J4.14 (CK-); also elsewhere on the board
/HDMI1_CLK_P: J4.12 (CK+); also elsewhere on the board
/HDMI1_HOTPLUG: J4.1 (HPD/HEAC-); also elsewhere on the board
/HDMI1_SCL: J4.17 (SCL); also elsewhere on the board
/HDMI1_SDA: J4.18 (SDA); also elsewhere on the board
/HDMI1_TX0_N: J4.11 (D0-); also elsewhere on the board
/HDMI1_TX0_P: J4.9 (D0+); also elsewhere on the board
/HDMI1_TX1_N: J4.8 (D1-); also elsewhere on the board
/HDMI1_TX1_P: J4.6 (D1+); also elsewhere on the board
/HDMI1_TX2_N: J4.5 (D2-); also elsewhere on the board
/HDMI1_TX2_P: J4.3 (D2+); also elsewhere on the board
/hdmi/HDMI_5v: C9.1, J3.19 (+5V), J4.19 (+5V), U6.2 (OUT)
GND: C8.2, C9.2, J3.4 (D2S), J3.7 (D1S), J3.10 (D0S), J3.13 (CKS), J3.16 (GND), J3.SHLD (SH), J4.4 (D2S), J4.7 (D1S), J4.10 (D0S), J4.13 (CKS), J4.16 (GND), J4.SHLD (SH), U6.3 (GND); also elsewhere on the board

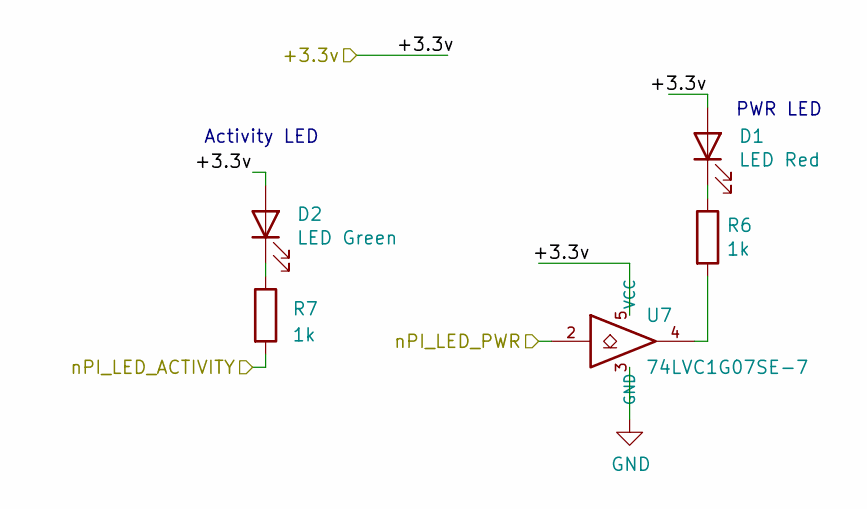
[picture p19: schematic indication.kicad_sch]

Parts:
D1: LED Red; LED_0603_1608Metric
D2: LED Green; LED_0603_1608Metric
R6, R7: 1k; R_0603_1608Metric
U7: 74LVC1G07SE-7; SOT-353_SC-70-5; Part Description Buffer, Non-Inverting 1 Element 1 Bit p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

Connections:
/+3.3v: D1.2 (A), D2.2 (A), U7.5 (VCC); also elsewhere on the board
/nPI_LED_ACTIVITY: R7.2; also elsewhere on the board
/nPI_LED_PWR: U7.2; also elsewhere on the board
GND: U7.3 (GND); also elsewhere on the board
unnamed: D1.1 (K), R6.1
unnamed: D2.1 (K), R7.1
unnamed: R6.2, U7.4

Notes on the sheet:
Activity LED
PWR LED

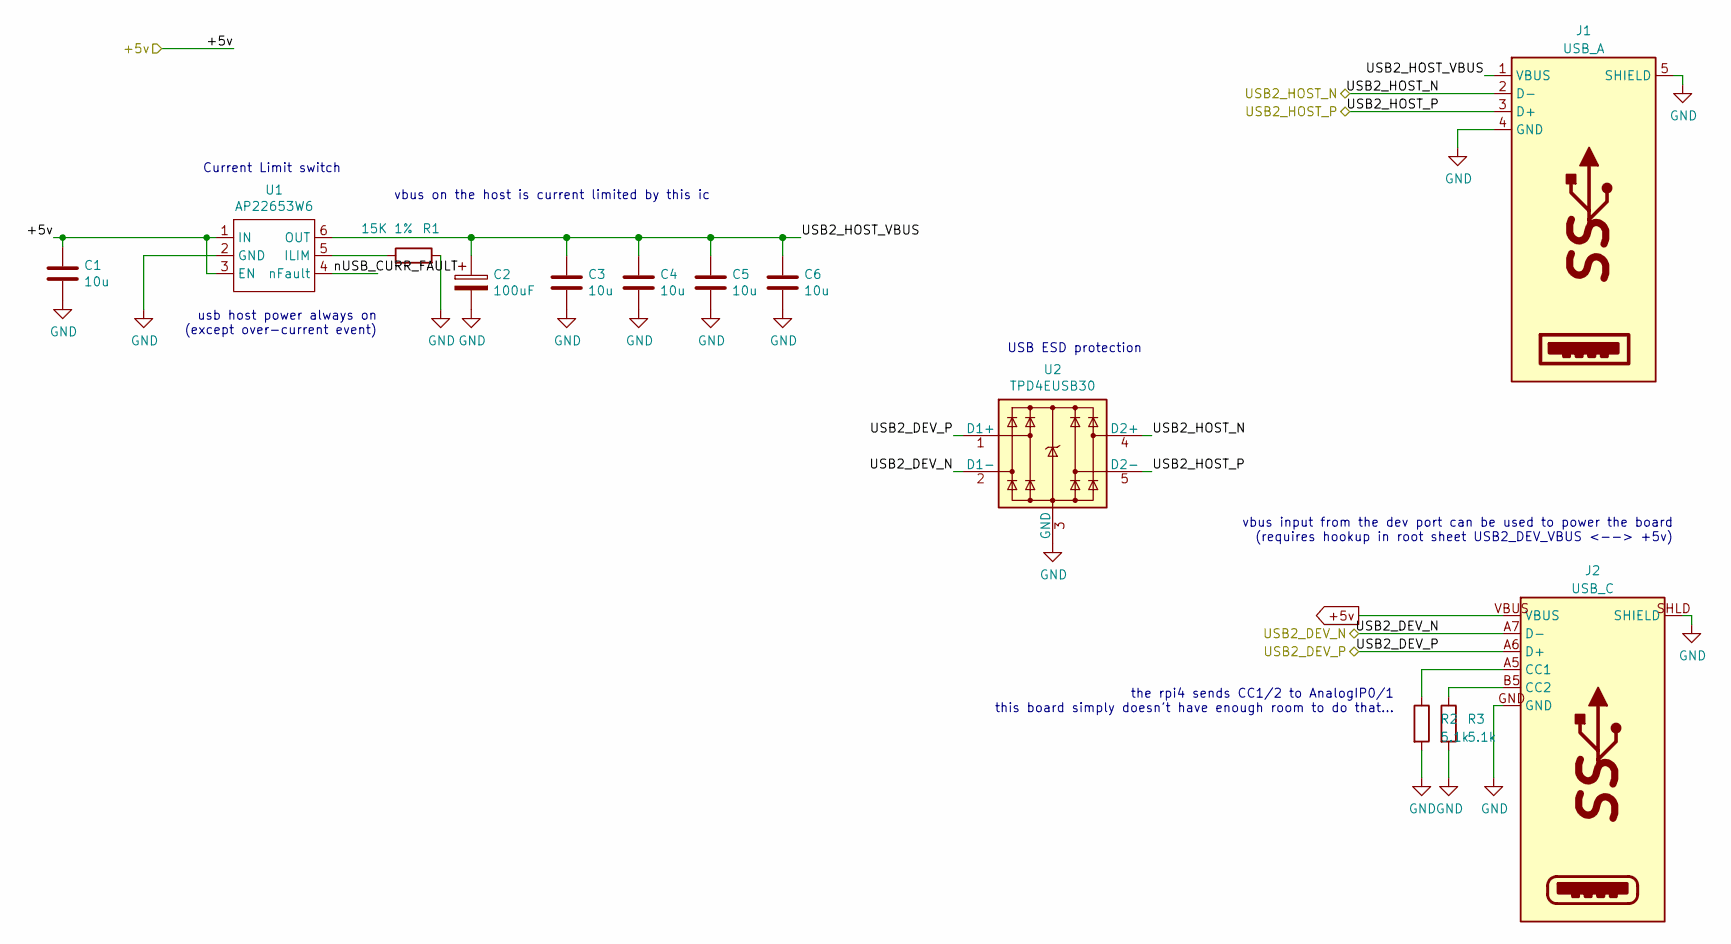
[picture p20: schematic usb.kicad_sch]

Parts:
C1, C3, C4, C5, C6: 10u; C_0603_1608Metric
C2: 100uF; C_0805_2012Metric_Pad1.18x1.45mm_HandSolder; Part Description Capacitor, SP-Cap, 100u, 6.3V, 15mR ESR
J1: USB_A; AU-Y1006
J2: USB_C; USB4105-GF-A
R1: 15K 1%; R_0603_1608Metric
R2, R3: 5.1k; R_0603_1608Metric
U1: AP22653W6; SOT-23-6; Part Description Power Switch/Driver 1:1 P-Channel 2.1A 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
U2: TPD4EUSB30; USON-10_2.5x1.0mm_P0.5mm; Part Description Quad TVS diode for high speed signals (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

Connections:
+5v: C1.1, J2.VBUS, U1.1 (IN), U1.3 (EN); also elsewhere on the board
/USB2_DEV_N: J2.A7 (D-), J2.B7 (D-), U2.2 (D1-), U2.9; also elsewhere on the board
/USB2_DEV_P: J2.A6 (D+), J2.B6 (D+), U2.1 (D1+), U2.10; also elsewhere on the board
/USB2_HOST_N: J1.2 (D-), U2.4 (D2+), U2.7; also elsewhere on the board
/USB2_HOST_P: J1.3 (D+), U2.5 (D2-), U2.6; also elsewhere on the board
/usb/USB2_HOST_VBUS: C2.1, C3.1, C4.1, C5.1, C6.1, J1.1 (VBUS), U1.6 (OUT)
/usb/nUSB_CURR_FAULT: U1.4 (nFault)
GND: C1.2, C2.2, C3.2, C4.2, C5.2, C6.2, J1.4 (GND), J1.5 (SHIELD), J2.GND, J2.SHLD (SHIELD), R1.2, R2.2, R3.2, U1.2 (GND), U2.3 (GND), U2.8 (GND); also elsewhere on the board
unnamed: J2.A5 (CC1), R2.1
unnamed: J2.B5 (CC2), R3.1
unnamed: R1.1, U1.5 (ILIM)

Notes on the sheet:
Current Limit switch
usb host power always on (except over-current event)
vbus on the host is current limited by this ic
USB ESD protection
the rpi4 sends CC1/2 to AnalogIP0/1 this board simply doesn't have enough room to do that...
vbus input from the dev port can be used to power the board (requires hookup in root sheet USB2_DEV_VBUS <--> +5v)

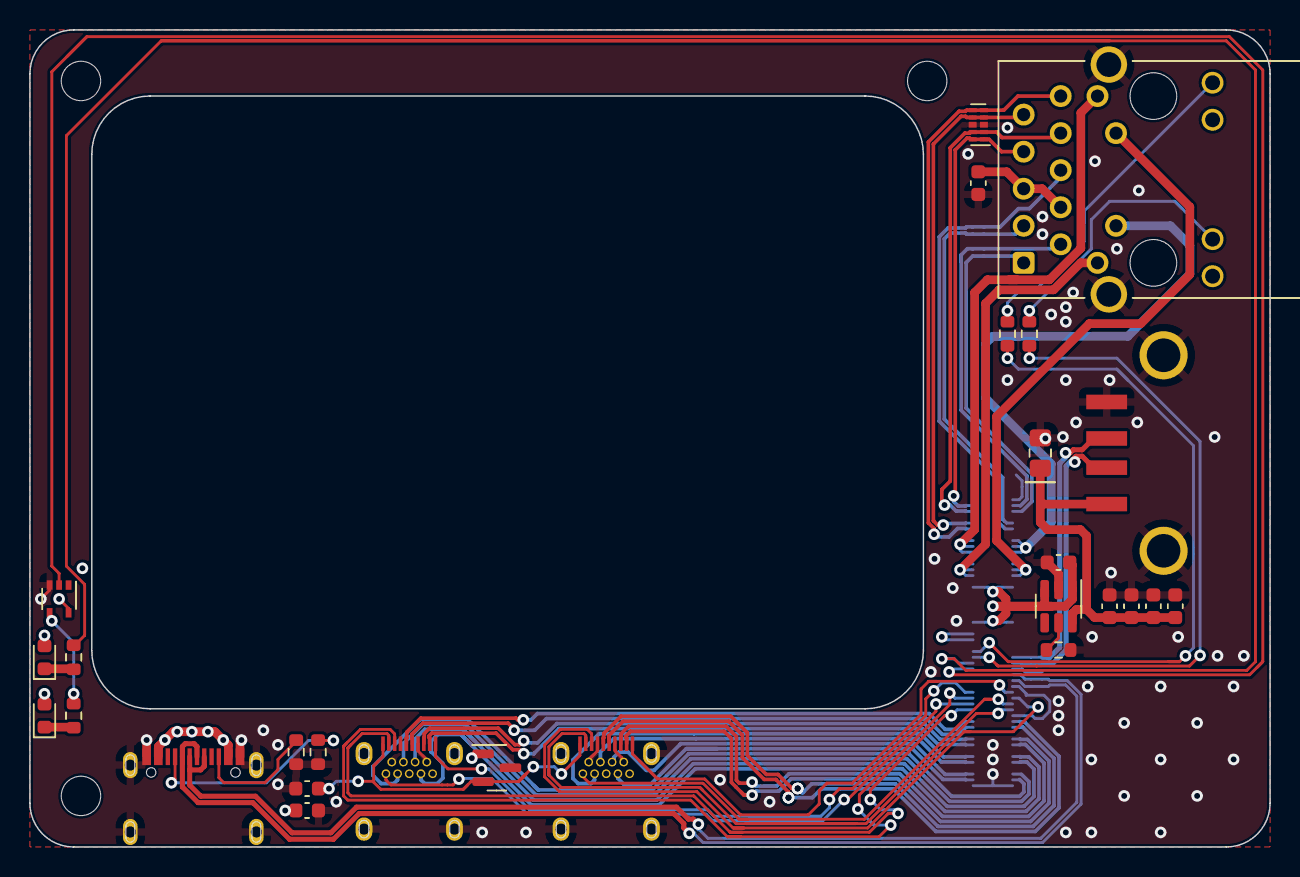
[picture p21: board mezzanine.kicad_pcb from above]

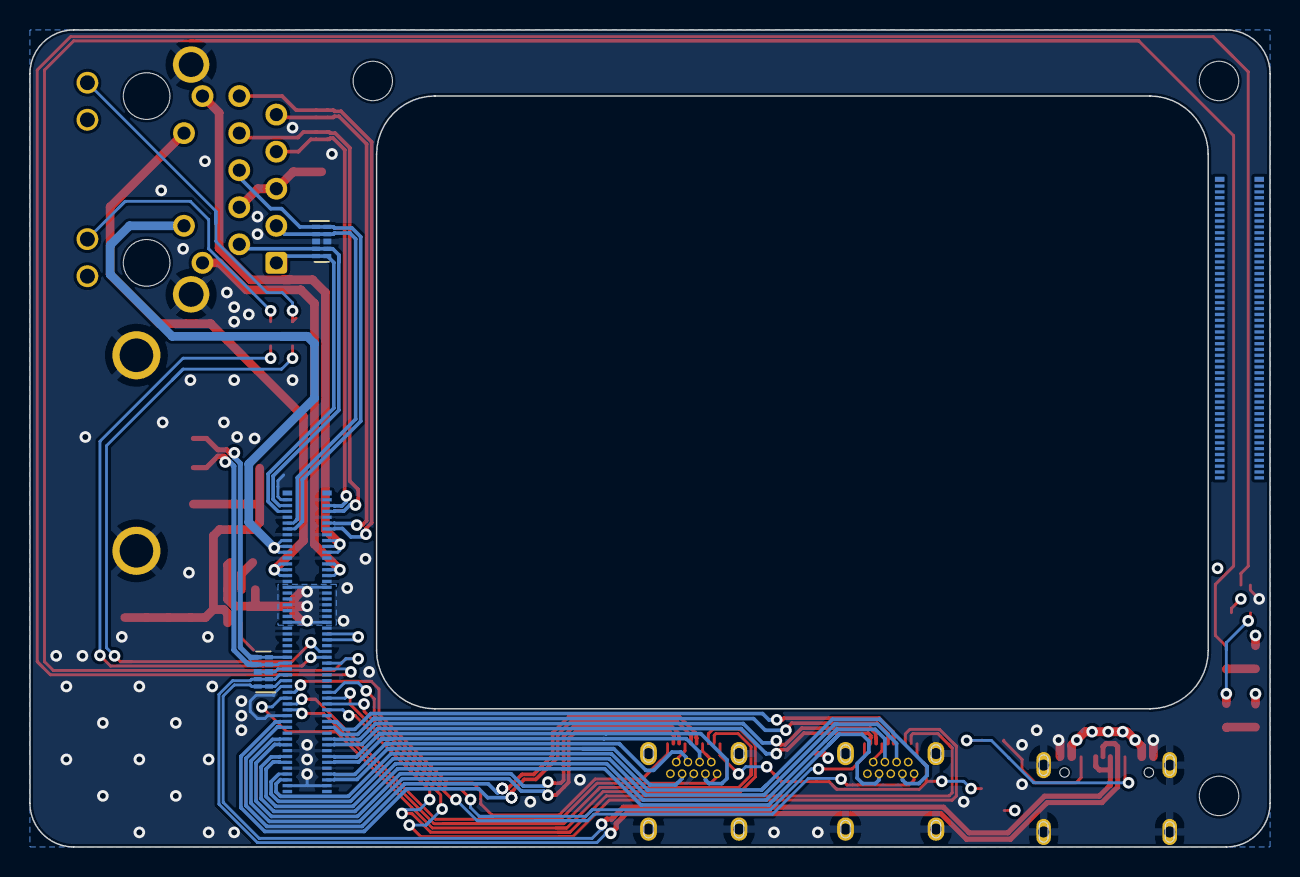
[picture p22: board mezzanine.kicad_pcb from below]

Board: 4 copper layers, 85.0 x 56.0 mm, 34 parts (4 on the bottom side), 58 nets.

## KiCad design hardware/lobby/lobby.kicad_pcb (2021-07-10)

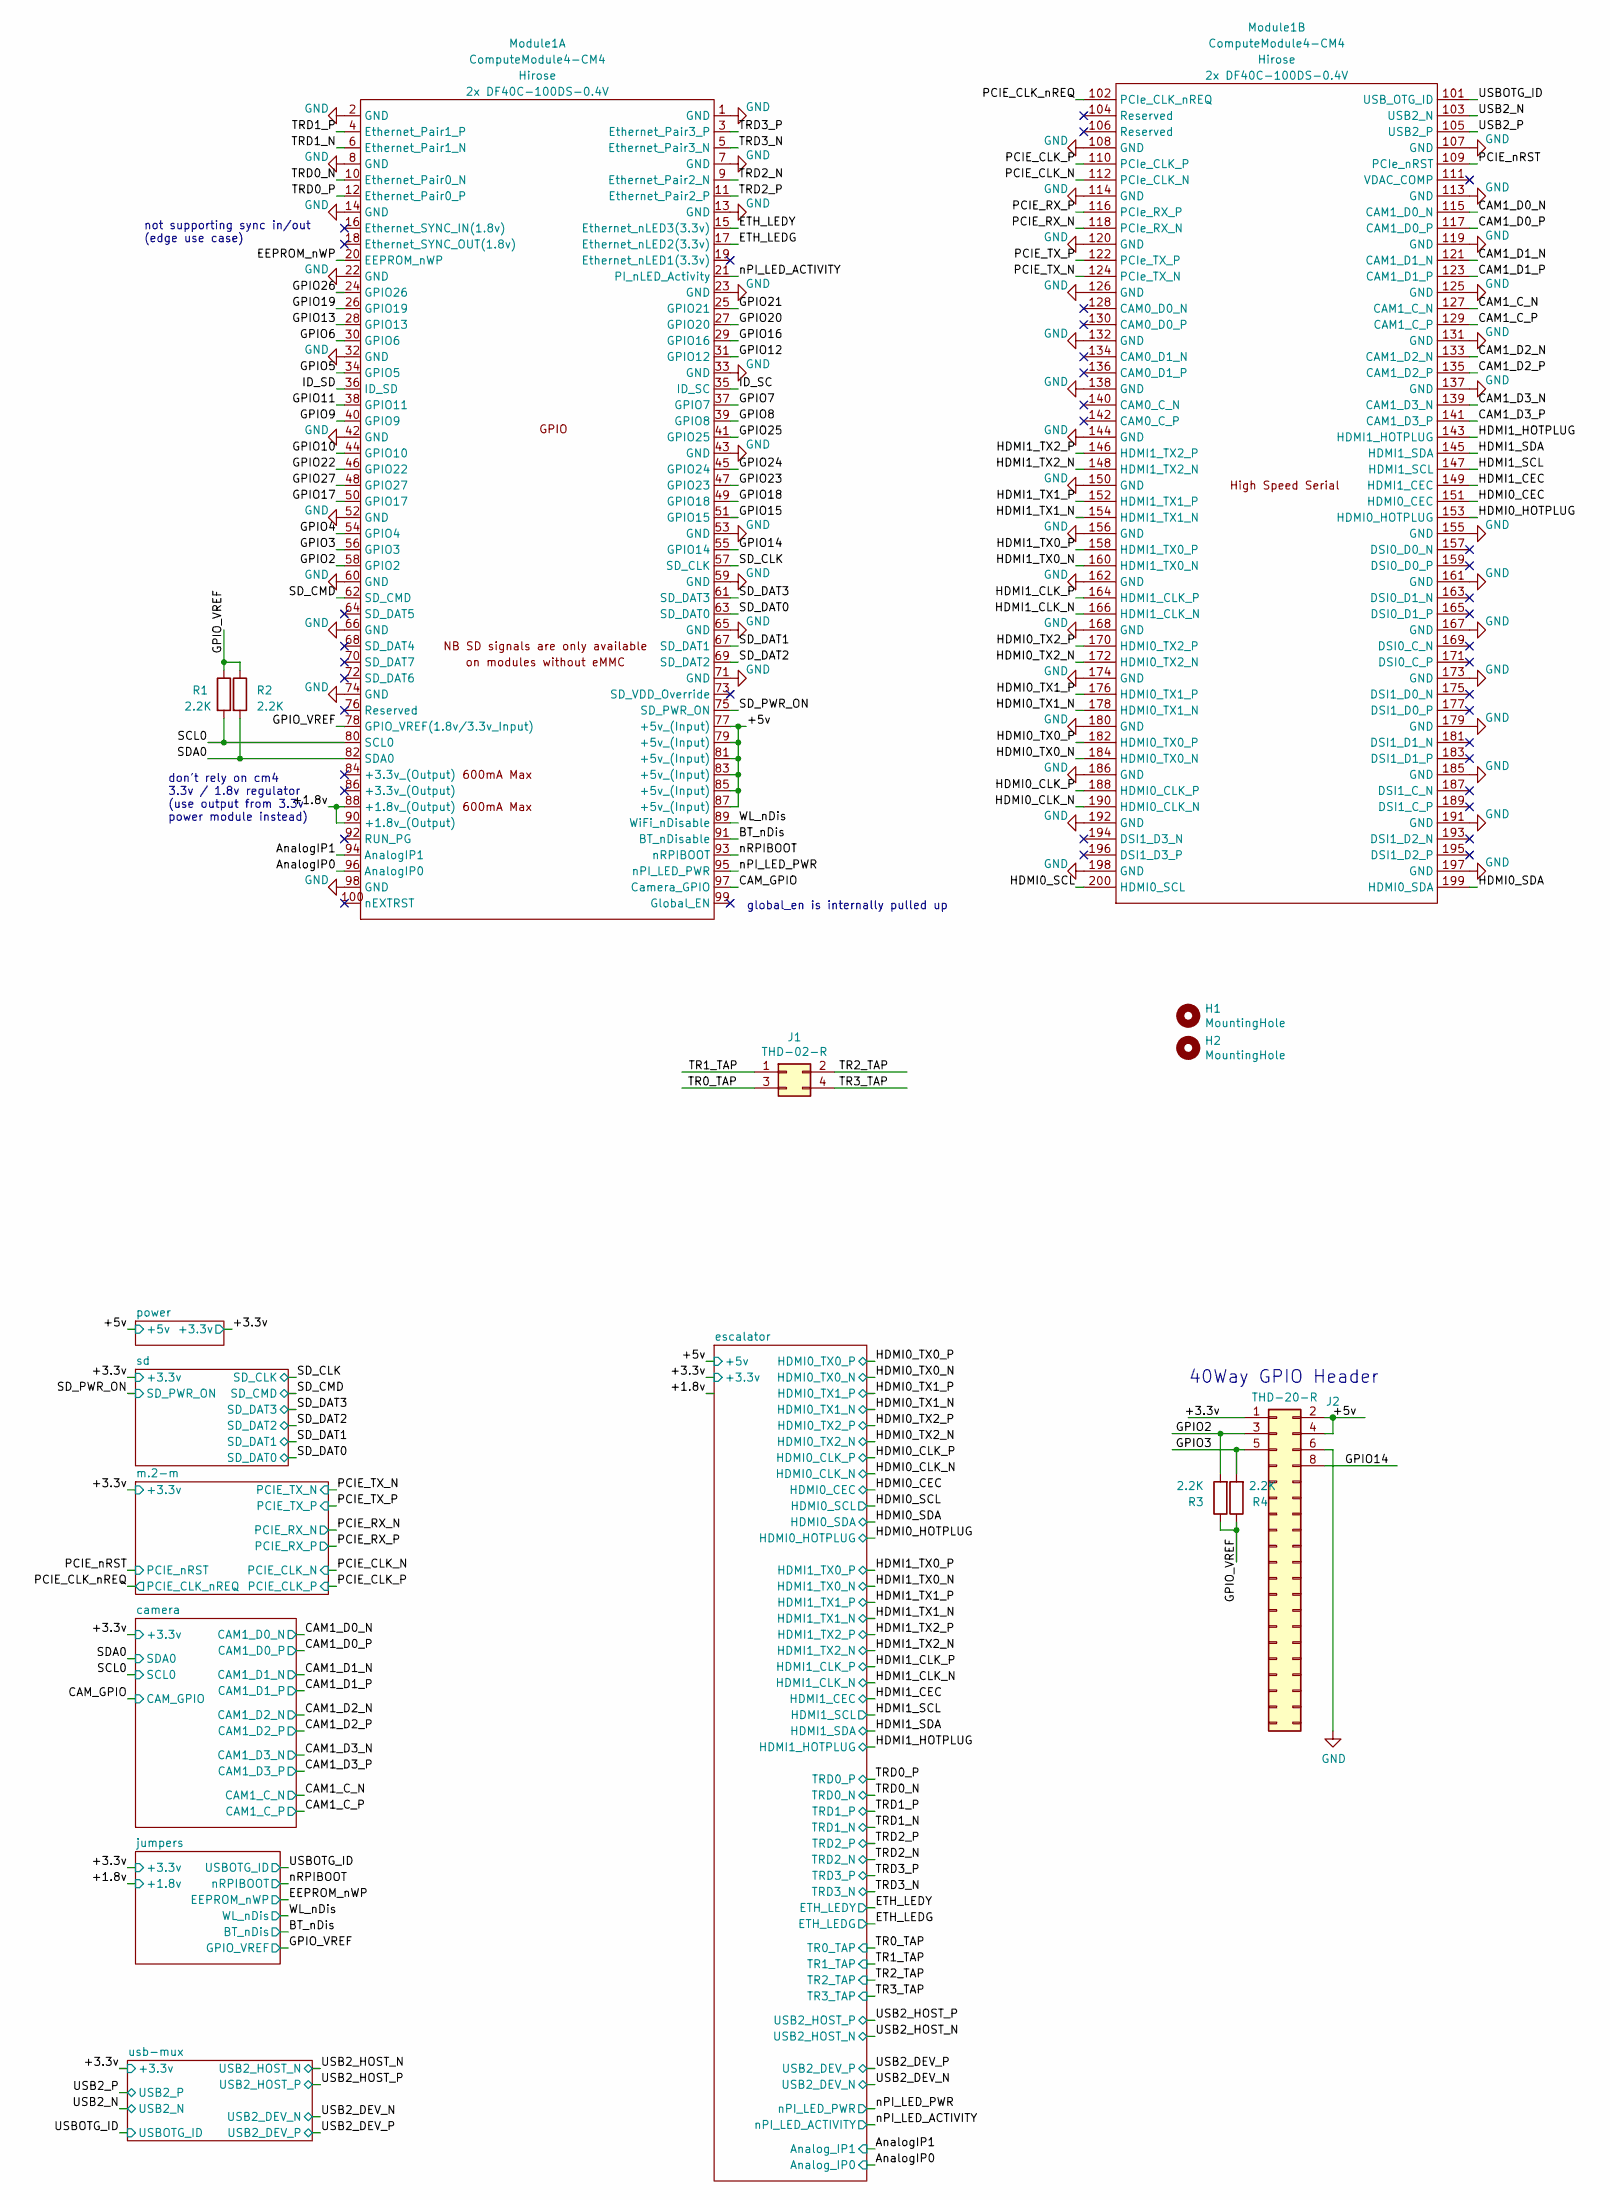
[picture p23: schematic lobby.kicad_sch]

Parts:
H1, H2: MountingHole; MountingHole_2.7mm_M2.5
J1: THD-02-R; PinHeader_2x02_P2.54mm_Vertical; Part Description PinHeader_2x02_P2.54mm_Vertical
J2: THD-20-R; rpi-40-just-power; Part Description PinHeader_2x20_P2.54mm_Vertical
Module1: ComputeModule4-CM4; Raspberry-Pi-4-Compute-Module-diagonal-mount-bl-ur
R1, R2, R3, R4: 2.2K; R_0603_1608Metric

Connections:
/+1.8v: Module1.88 (+1.8v_(Output)), Module1.90 (+1.8v_(Output)); also elsewhere on the board
/+3.3v: J2.1; also elsewhere on the board
/+5v: J2.2, J2.4, Module1.77 (+5v_(Input)), Module1.79 (+5v_(Input)), Module1.81 (+5v_(Input)), Module1.83 (+5v_(Input)), Module1.85 (+5v_(Input)), Module1.87 (+5v_(Input)); also elsewhere on the board
/AnalogIP0: Module1.96 (AnalogIP0); also elsewhere on the board
/AnalogIP1: Module1.94 (AnalogIP1); also elsewhere on the board
/BT_nDis: Module1.91 (BT_nDisable); also elsewhere on the board
/CAM1_C_N: Module1.127 (CAM1_C_N); also elsewhere on the board
/CAM1_C_P: Module1.129 (CAM1_C_P); also elsewhere on the board
/CAM1_D0_N: Module1.115 (CAM1_D0_N); also elsewhere on the board
/CAM1_D0_P: Module1.117 (CAM1_D0_P); also elsewhere on the board
/CAM1_D1_N: Module1.121 (CAM1_D1_N); also elsewhere on the board
/CAM1_D1_P: Module1.123 (CAM1_D1_P); also elsewhere on the board
/CAM1_D2_N: Module1.133 (CAM1_D2_N); also elsewhere on the board
/CAM1_D2_P: Module1.135 (CAM1_D2_P); also elsewhere on the board
/CAM1_D3_N: Module1.139 (CAM1_D3_N); also elsewhere on the board
/CAM1_D3_P: Module1.141 (CAM1_D3_P); also elsewhere on the board
/CAM_GPIO: Module1.97 (Camera_GPIO); also elsewhere on the board
/EEPROM_nWP: Module1.20 (EEPROM_nWP); also elsewhere on the board
/ETH_LEDG: Module1.17 (Ethernet_nLED2(3.3v)); also elsewhere on the board
/ETH_LEDY: Module1.15 (Ethernet_nLED3(3.3v)); also elsewhere on the board
/GPIO2: J2.3, Module1.58 (GPIO2), R3.2
/GPIO3: J2.5, Module1.56 (GPIO3), R4.2
/GPIO4: Module1.54 (GPIO4)
/GPIO5: Module1.34 (GPIO5)
/GPIO6: Module1.30 (GPIO6)
/GPIO7: Module1.37 (GPIO7)
/GPIO8: Module1.39 (GPIO8)
/GPIO9: Module1.40 (GPIO9)
/GPIO10: Module1.44 (GPIO10)
/GPIO11: Module1.38 (GPIO11)
/GPIO12: Module1.31 (GPIO12)
/GPIO13: Module1.28 (GPIO13)
/GPIO14: J2.8, Module1.55 (GPIO14)
/GPIO15: Module1.51 (GPIO15)
/GPIO16: Module1.29 (GPIO16)
/GPIO17: Module1.50 (GPIO17)
/GPIO18: Module1.49 (GPIO18)
/GPIO19: Module1.26 (GPIO19)
/GPIO20: Module1.27 (GPIO20)
/GPIO21: Module1.25 (GPIO21)
/GPIO22: Module1.46 (GPIO22)
/GPIO23: Module1.47 (GPIO23)
/GPIO24: Module1.45 (GPIO24)
/GPIO25: Module1.41 (GPIO25)
/GPIO26: Module1.24 (GPIO26)
/GPIO27: Module1.48 (GPIO27)
/GPIO_VREF: Module1.78 (GPIO_VREF(1.8v/3.3v_Input)), R1.1, R2.1, R3.1, R4.1; also elsewhere on the board
/HDMI0_CEC: Module1.151 (HDMI0_CEC); also elsewhere on the board
/HDMI0_CLK_N: Module1.190 (HDMI0_CLK_N); also elsewhere on the board
/HDMI0_CLK_P: Module1.188 (HDMI0_CLK_P); also elsewhere on the board
/HDMI0_HOTPLUG: Module1.153 (HDMI0_HOTPLUG); also elsewhere on the board
/HDMI0_SCL: Module1.200 (HDMI0_SCL); also elsewhere on the board
/HDMI0_SDA: Module1.199 (HDMI0_SDA); also elsewhere on the board
/HDMI0_TX0_N: Module1.184 (HDMI0_TX0_N); also elsewhere on the board
/HDMI0_TX0_P: Module1.182 (HDMI0_TX0_P); also elsewhere on the board
/HDMI0_TX1_N: Module1.178 (HDMI0_TX1_N); also elsewhere on the board
/HDMI0_TX1_P: Module1.176 (HDMI0_TX1_P); also elsewhere on the board
/HDMI0_TX2_N: Module1.172 (HDMI0_TX2_N); also elsewhere on the board
/HDMI0_TX2_P: Module1.170 (HDMI0_TX2_P); also elsewhere on the board
/HDMI1_CEC: Module1.149 (HDMI1_CEC); also elsewhere on the board
/HDMI1_CLK_N: Module1.166 (HDMI1_CLK_N); also elsewhere on the board
/HDMI1_CLK_P: Module1.164 (HDMI1_CLK_P); also elsewhere on the board
/HDMI1_HOTPLUG: Module1.143 (HDMI1_HOTPLUG); also elsewhere on the board
/HDMI1_SCL: Module1.147 (HDMI1_SCL); also elsewhere on the board
/HDMI1_SDA: Module1.145 (HDMI1_SDA); also elsewhere on the board
/HDMI1_TX0_N: Module1.160 (HDMI1_TX0_N); also elsewhere on the board
/HDMI1_TX0_P: Module1.158 (HDMI1_TX0_P); also elsewhere on the board
/HDMI1_TX1_N: Module1.154 (HDMI1_TX1_N); also elsewhere on the board
/HDMI1_TX1_P: Module1.152 (HDMI1_TX1_P); also elsewhere on the board
/HDMI1_TX2_N: Module1.148 (HDMI1_TX2_N); also elsewhere on the board
/HDMI1_TX2_P: Module1.146 (HDMI1_TX2_P); also elsewhere on the board
/ID_SC: Module1.35 (ID_SC)
/ID_SD: Module1.36 (ID_SD)
/PCIE_CLK_N: Module1.112 (PCIe_CLK_N); also elsewhere on the board
/PCIE_CLK_P: Module1.110 (PCIe_CLK_P); also elsewhere on the board
/PCIE_CLK_nREQ: Module1.102 (PCIe_CLK_nREQ); also elsewhere on the board
/PCIE_RX_N: Module1.118 (PCIe_RX_N); also elsewhere on the board
/PCIE_RX_P: Module1.116 (PCIe_RX_P); also elsewhere on the board
/PCIE_TX_N: Module1.124 (PCIe_TX_N); also elsewhere on the board
/PCIE_TX_P: Module1.122 (PCIe_TX_P); also elsewhere on the board
/PCIE_nRST: Module1.109 (PCIe_nRST); also elsewhere on the board
/SCL0: Module1.80 (SCL0), R1.2; also elsewhere on the board
/SDA0: Module1.82 (SDA0), R2.2; also elsewhere on the board
/SD_CLK: Module1.57 (SD_CLK); also elsewhere on the board
/SD_CMD: Module1.62 (SD_CMD); also elsewhere on the board
/SD_DAT0: Module1.63 (SD_DAT0); also elsewhere on the board
/SD_DAT1: Module1.67 (SD_DAT1); also elsewhere on the board
/SD_DAT2: Module1.69 (SD_DAT2); also elsewhere on the board
/SD_DAT3: Module1.61 (SD_DAT3); also elsewhere on the board
/SD_PWR_ON: Module1.75 (SD_PWR_ON); also elsewhere on the board
/TR0_TAP: J1.3; also elsewhere on the board
/TR1_TAP: J1.1; also elsewhere on the board
/TR2_TAP: J1.2; also elsewhere on the board
/TR3_TAP: J1.4; also elsewhere on the board
/TRD0_N: Module1.10 (Ethernet_Pair0_N); also elsewhere on the board
/TRD0_P: Module1.12 (Ethernet_Pair0_P); also elsewhere on the board
/TRD1_N: Module1.6 (Ethernet_Pair1_N); also elsewhere on the board
/TRD1_P: Module1.4 (Ethernet_Pair1_P); also elsewhere on the board
/TRD2_N: Module1.9 (Ethernet_Pair2_N); also elsewhere on the board
/TRD2_P: Module1.11 (Ethernet_Pair2_P); also elsewhere on the board
/TRD3_N: Module1.5 (Ethernet_Pair3_N); also elsewhere on the board
/TRD3_P: Module1.3 (Ethernet_Pair3_P); also elsewhere on the board
/USB2_N: Module1.103 (USB2_N); also elsewhere on the board
/USB2_P: Module1.105 (USB2_P); also elsewhere on the board
/USBOTG_ID: Module1.101 (USB_OTG_ID); also elsewhere on the board
/WL_nDis: Module1.89 (WiFi_nDisable); also elsewhere on the board
/nPI_LED_ACTIVITY: Module1.21 (PI_nLED_Activity); also elsewhere on the board
/nPI_LED_PWR: Module1.95 (nPI_LED_PWR); also elsewhere on the board
/nRPIBOOT: Module1.93 (nRPIBOOT); also elsewhere on the board
GND: J2.6, Module1.1 (GND), Module1.2 (GND), Module1.7 (GND), Module1.8 (GND), Module1.13 (GND), Module1.14 (GND), Module1.22 (GND), Module1.23 (GND), Module1.32 (GND), Module1.33 (GND), Module1.42 (GND), Module1.43 (GND), Module1.52 (GND), Module1.53 (GND), Module1.59 (GND), Module1.60 (GND), Module1.65 (GND), Module1.66 (GND), Module1.71 (GND), Module1.74 (GND), Module1.98 (GND), Module1.107 (GND), Module1.108 (GND), Module1.113 (GND), Module1.114 (GND), Module1.119 (GND), Module1.120 (GND), Module1.125 (GND), Module1.126 (GND), Module1.131 (GND), Module1.132 (GND), Module1.137 (GND), Module1.138 (GND), Module1.144 (GND), Module1.150 (GND), Module1.155 (GND), Module1.156 (GND), Module1.161 (GND), Module1.162 (GND), Module1.167 (GND), Module1.168 (GND), Module1.173 (GND), Module1.174 (GND), Module1.179 (GND), Module1.180 (GND), Module1.185 (GND), Module1.186 (GND), Module1.191 (GND), Module1.192 (GND), Module1.197 (GND), Module1.198 (GND); also elsewhere on the board

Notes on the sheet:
not supporting sync in/out (edge use case)
don't rely on cm4 3.3v / 1.8v regulator (use output from 3.3v power module instead)
global_en is internally pulled up
40Way GPIO Header

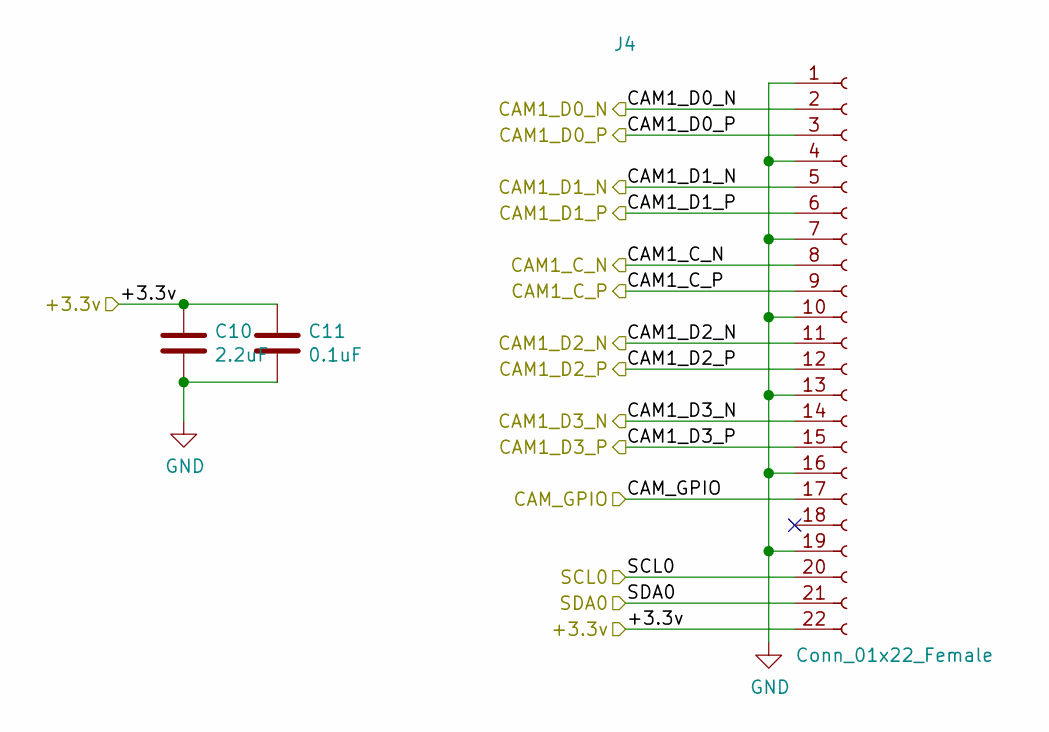
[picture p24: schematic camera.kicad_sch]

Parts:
C10: 2.2uF; C_0603_1608Metric; Part Description 10uF 10% 10V Ceramic Capacitor X7R 0805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
C11: 0.1uF; C_0603_1608Metric; Part Description 10uF 10% 10V Ceramic Capacitor X7R 0805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
J4: Conn_01x22_Female; SFV22R-2STE1HLF; Part Description 22 Position FFC, FPC Connector Contacts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

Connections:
/+3.3v: C10.1, C11.1, J4.22; also elsewhere on the board
/CAM1_C_N: J4.8; also elsewhere on the board
/CAM1_C_P: J4.9; also elsewhere on the board
/CAM1_D0_N: J4.2; also elsewhere on the board
/CAM1_D0_P: J4.3; also elsewhere on the board
/CAM1_D1_N: J4.5; also elsewhere on the board
/CAM1_D1_P: J4.6; also elsewhere on the board
/CAM1_D2_N: J4.11; also elsewhere on the board
/CAM1_D2_P: J4.12; also elsewhere on the board
/CAM1_D3_N: J4.14; also elsewhere on the board
/CAM1_D3_P: J4.15; also elsewhere on the board
/CAM_GPIO: J4.17; also elsewhere on the board
/SCL0: J4.20; also elsewhere on the board
/SDA0: J4.21; also elsewhere on the board
GND: C10.2, C11.2, J4.1, J4.4, J4.7, J4.10, J4.13, J4.16, J4.19; also elsewhere on the board

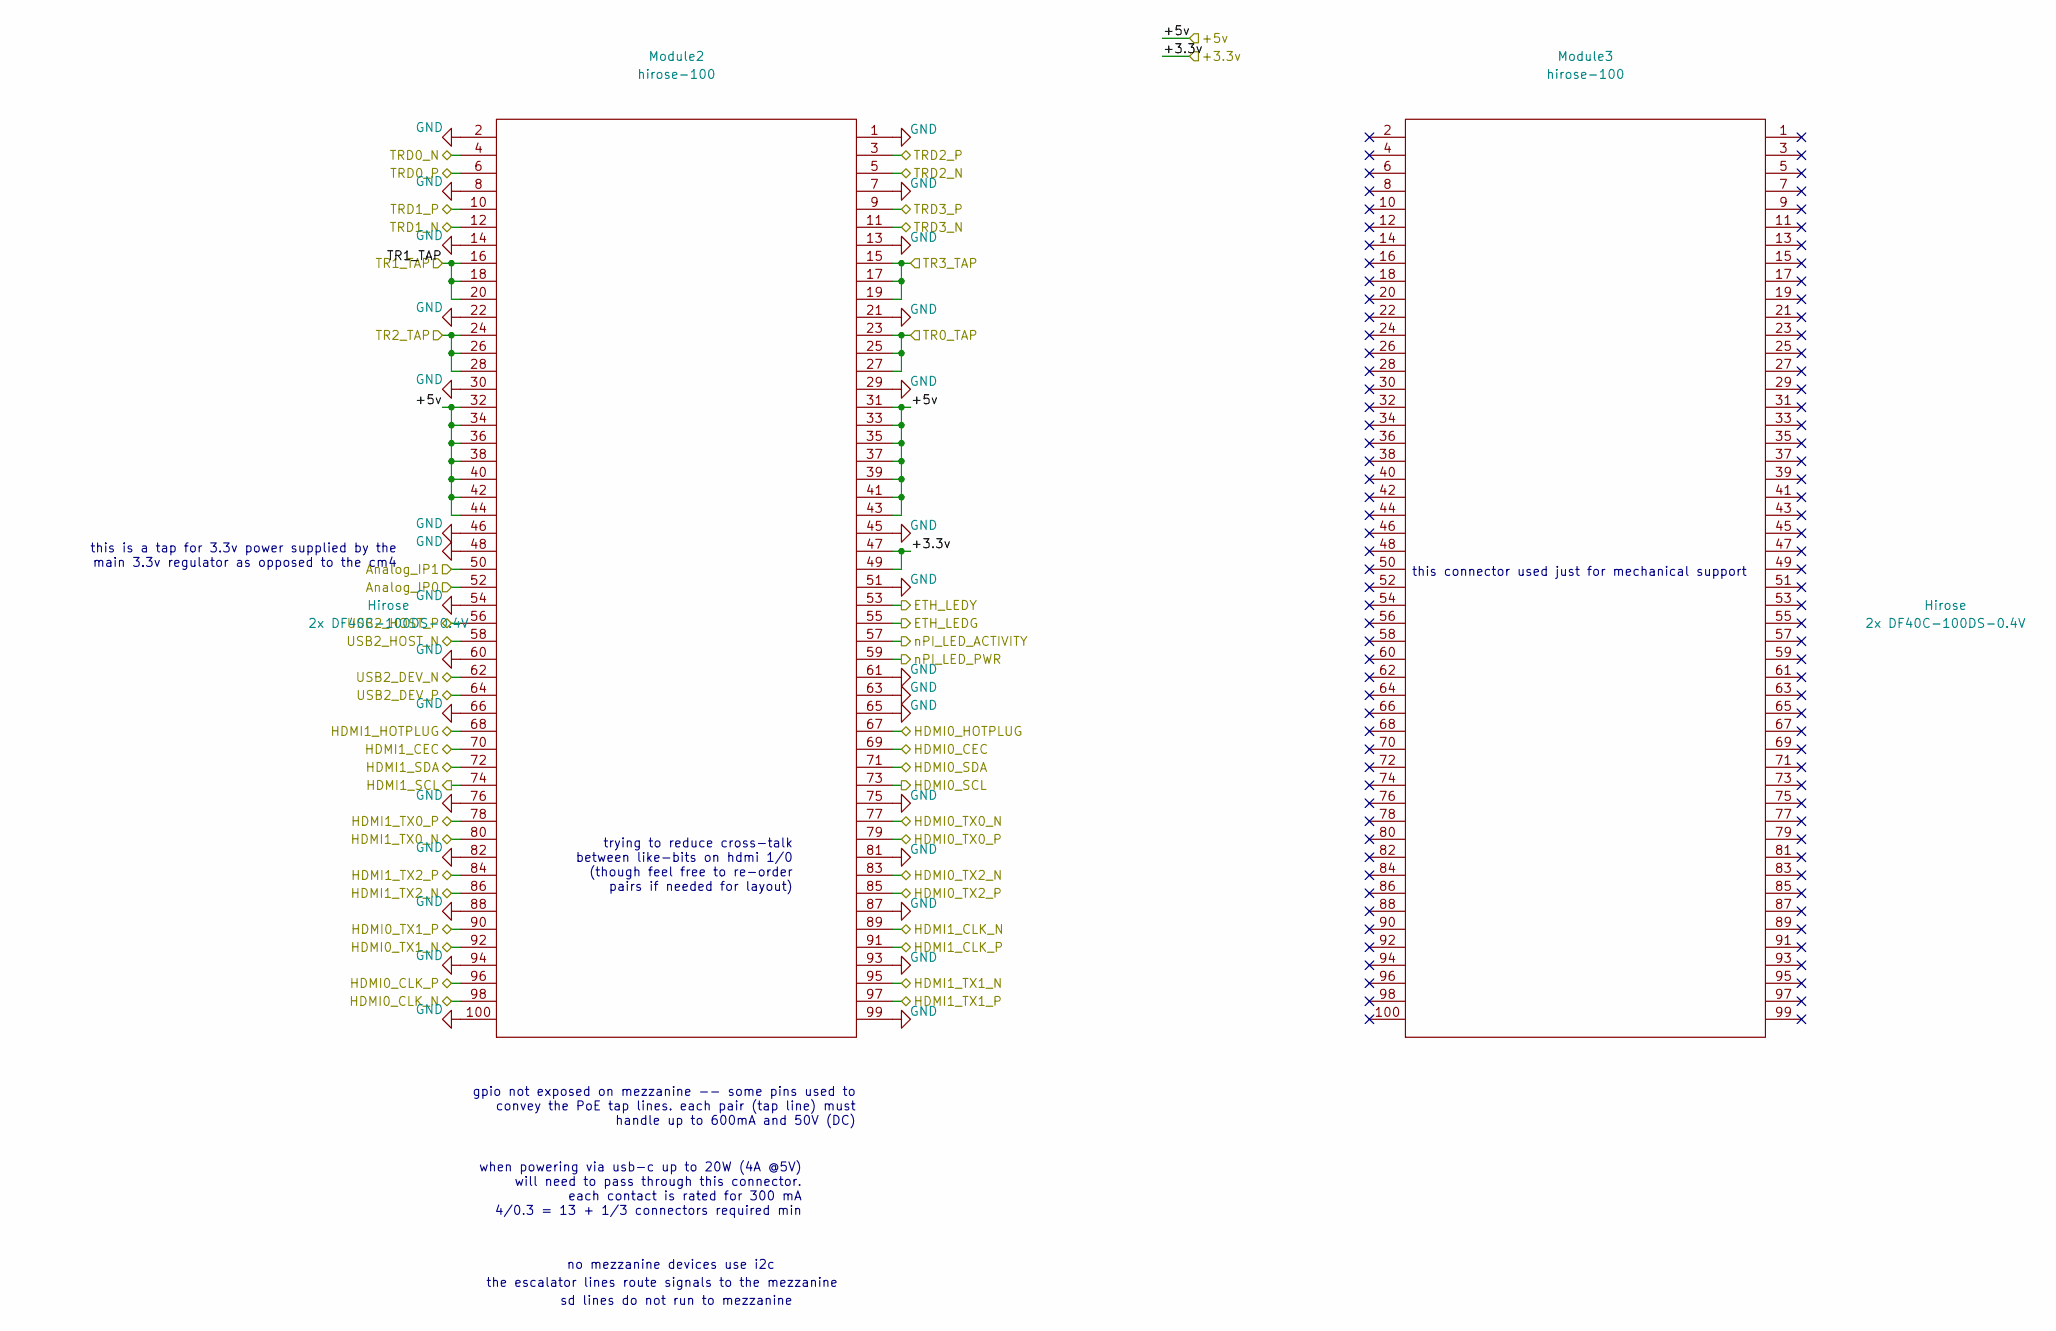
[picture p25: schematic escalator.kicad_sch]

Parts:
Module2, Module3: hirose-100; DF40C-100DS-0.4V(51)

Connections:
/+3.3v: Module2.47, Module2.49; also elsewhere on the board
/+5v: Module2.31, Module2.32, Module2.33, Module2.34, Module2.35, Module2.36, Module2.37, Module2.38, Module2.39, Module2.40, Module2.41, Module2.42, Module2.43, Module2.44; also elsewhere on the board
/AnalogIP0: Module2.52; also elsewhere on the board
/AnalogIP1: Module2.50; also elsewhere on the board
/ETH_LEDG: Module2.55; also elsewhere on the board
/ETH_LEDY: Module2.53; also elsewhere on the board
/HDMI0_CEC: Module2.69; also elsewhere on the board
/HDMI0_CLK_N: Module2.98; also elsewhere on the board
/HDMI0_CLK_P: Module2.96; also elsewhere on the board
/HDMI0_HOTPLUG: Module2.67; also elsewhere on the board
/HDMI0_SCL: Module2.73; also elsewhere on the board
/HDMI0_SDA: Module2.71; also elsewhere on the board
/HDMI0_TX0_N: Module2.77; also elsewhere on the board
/HDMI0_TX0_P: Module2.79; also elsewhere on the board
/HDMI0_TX1_N: Module2.92; also elsewhere on the board
/HDMI0_TX1_P: Module2.90; also elsewhere on the board
/HDMI0_TX2_N: Module2.83; also elsewhere on the board
/HDMI0_TX2_P: Module2.85; also elsewhere on the board
/HDMI1_CEC: Module2.70; also elsewhere on the board
/HDMI1_CLK_N: Module2.89; also elsewhere on the board
/HDMI1_CLK_P: Module2.91; also elsewhere on the board
/HDMI1_HOTPLUG: Module2.68; also elsewhere on the board
/HDMI1_SCL: Module2.74; also elsewhere on the board
/HDMI1_SDA: Module2.72; also elsewhere on the board
/HDMI1_TX0_N: Module2.80; also elsewhere on the board
/HDMI1_TX0_P: Module2.78; also elsewhere on the board
/HDMI1_TX1_N: Module2.95; also elsewhere on the board
/HDMI1_TX1_P: Module2.97; also elsewhere on the board
/HDMI1_TX2_N: Module2.86; also elsewhere on the board
/HDMI1_TX2_P: Module2.84; also elsewhere on the board
/TR0_TAP: Module2.23, Module2.25, Module2.27; also elsewhere on the board
/TR1_TAP: Module2.16, Module2.18, Module2.20; also elsewhere on the board
/TR2_TAP: Module2.24, Module2.26, Module2.28; also elsewhere on the board
/TR3_TAP: Module2.15, Module2.17, Module2.19; also elsewhere on the board
/TRD0_N: Module2.4; also elsewhere on the board
/TRD0_P: Module2.6; also elsewhere on the board
/TRD1_N: Module2.12; also elsewhere on the board
/TRD1_P: Module2.10; also elsewhere on the board
/TRD2_N: Module2.5; also elsewhere on the board
/TRD2_P: Module2.3; also elsewhere on the board
/TRD3_N: Module2.11; also elsewhere on the board
/TRD3_P: Module2.9; also elsewhere on the board
/USB2_DEV_N: Module2.62; also elsewhere on the board
/USB2_DEV_P: Module2.64; also elsewhere on the board
/USB2_HOST_N: Module2.58; also elsewhere on the board
/USB2_HOST_P: Module2.56; also elsewhere on the board
/nPI_LED_ACTIVITY: Module2.57; also elsewhere on the board
/nPI_LED_PWR: Module2.59; also elsewhere on the board
GND: Module2.1, Module2.2, Module2.7, Module2.8, Module2.13, Module2.14, Module2.21, Module2.22, Module2.29, Module2.30, Module2.45, Module2.46, Module2.48, Module2.51, Module2.54, Module2.60, Module2.61, Module2.63, Module2.65, Module2.66, Module2.75, Module2.76, Module2.81, Module2.82, Module2.87, Module2.88, Module2.93, Module2.94, Module2.99, Module2.100; also elsewhere on the board

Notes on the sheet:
this is a tap for 3.3v power supplied by the main 3.3v regulator as opposed to the cm4
sd lines do not run to mezzanine
no mezzanine devices use i2c
trying to reduce cross-talk between like-bits on hdmi 1/0 (though feel free to re-order pairs if needed for layout)
when powering via usb-c up to 20W (4A @5V) will need to pass through this connector. each contact is rated for 300 mA 4/0.3 = 13 + 1/3 connectors required min
the escalator lines route signals to the mezzanine
gpio not exposed on mezzanine -- some pins used to convey the PoE tap lines. each pair (tap line) must handle up to 600mA and 50V (DC)
this connector used just for mechanical support

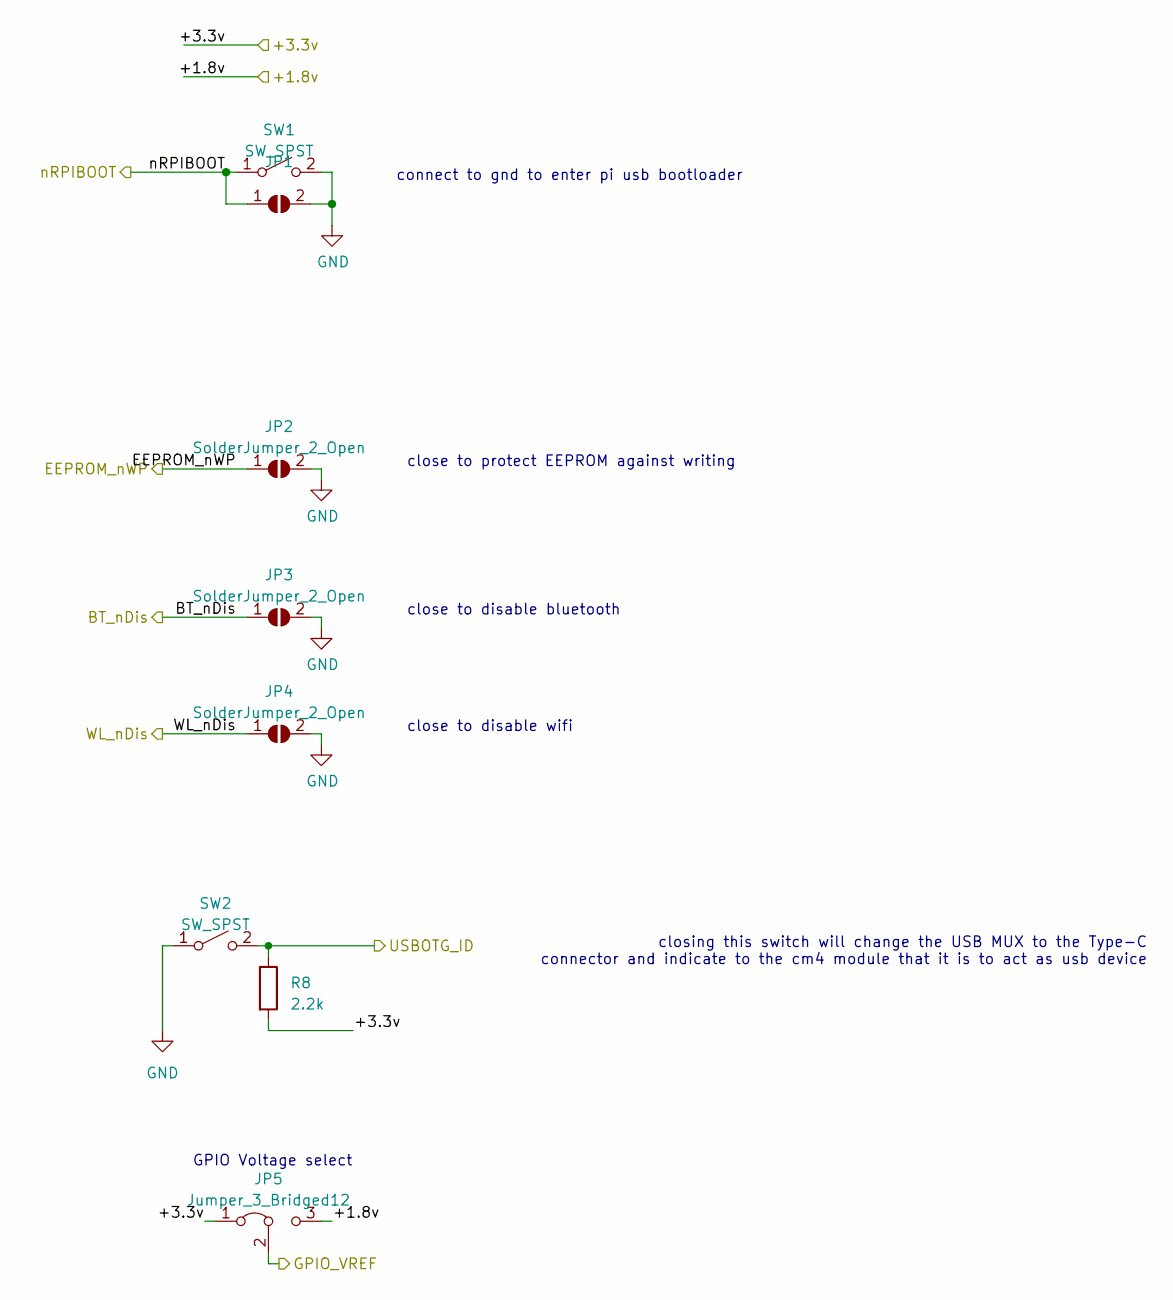
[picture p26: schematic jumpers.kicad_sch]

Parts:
JP1, JP2, JP3, JP4: SolderJumper_2_Open; SolderJumper-2_P1.3mm_Open_RoundedPad1.0x1.5mm
JP5: Jumper_3_Bridged12; SolderJumper-3_P1.3mm_Bridged12_RoundedPad1.0x1.5mm
R8: 2.2k; R_0603_1608Metric
SW1, SW2: SW_SPST; cus-12b

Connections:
/+1.8v: JP5.3 (B); also elsewhere on the board
/+3.3v: JP5.1 (A), R8.2; also elsewhere on the board
/BT_nDis: JP3.1 (A); also elsewhere on the board
/EEPROM_nWP: JP2.1 (A); also elsewhere on the board
/GPIO_VREF: JP5.2 (C); also elsewhere on the board
/USBOTG_ID: R8.1, SW2.2 (B); also elsewhere on the board
/WL_nDis: JP4.1 (A); also elsewhere on the board
/nRPIBOOT: JP1.1 (A), SW1.1 (A); also elsewhere on the board
GND: JP1.2 (B), JP2.2 (B), JP3.2 (B), JP4.2 (B), SW1.2 (B), SW2.1 (A); also elsewhere on the board

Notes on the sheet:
GPIO Voltage select
connect to gnd to enter pi usb bootloader
close to protect EEPROM against writing
close to disable bluetooth
close to disable wifi
closing this switch will change the USB MUX to the Type-C connector and indicate to the cm4 module that it is to act as usb device

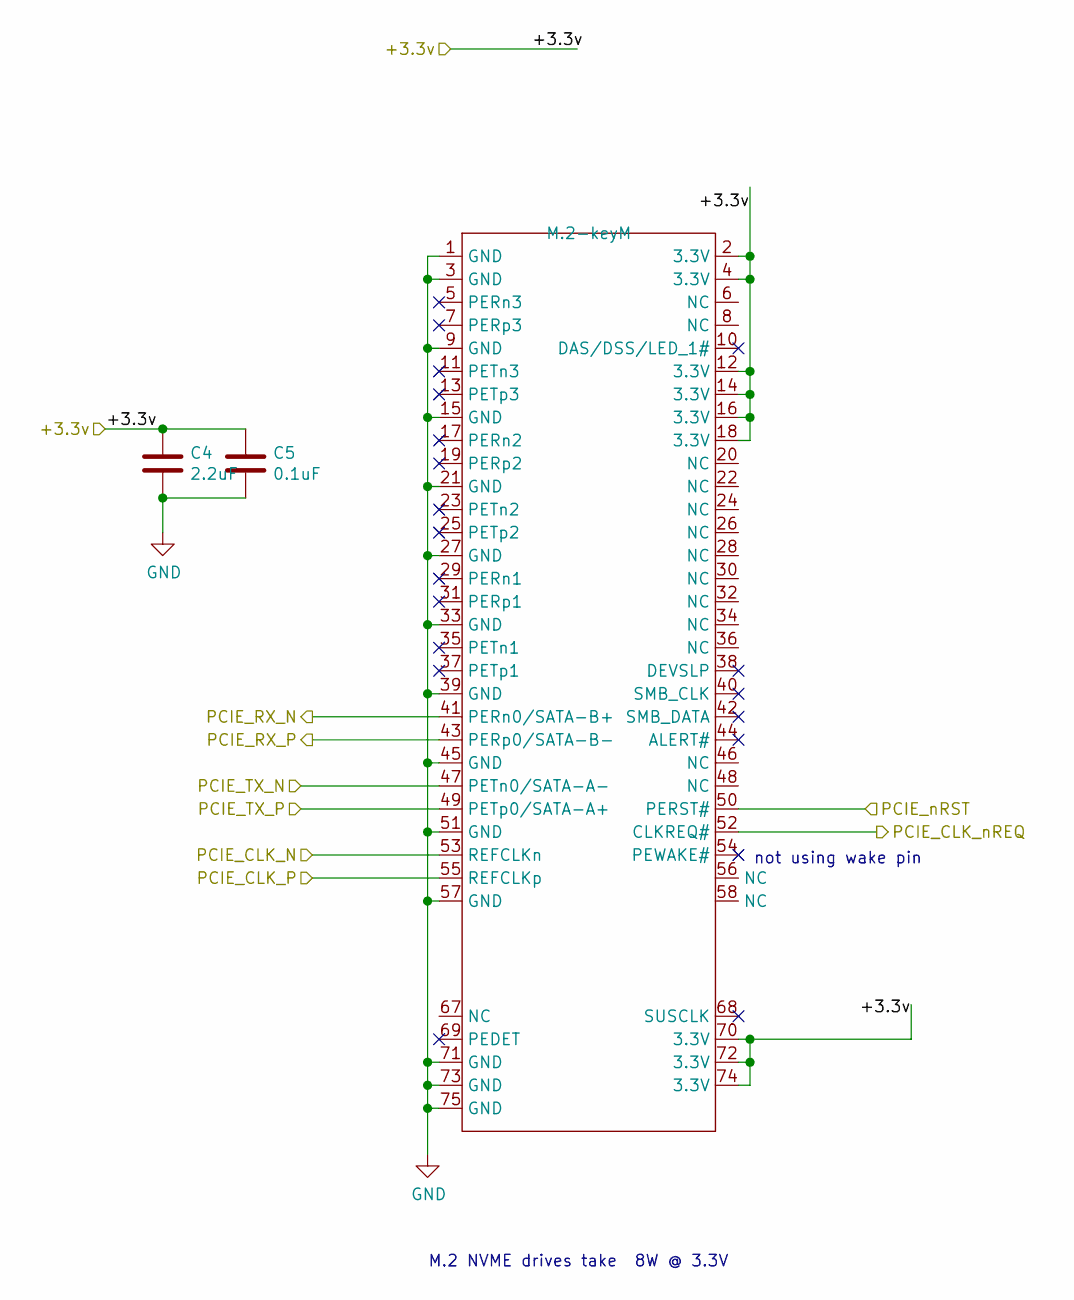
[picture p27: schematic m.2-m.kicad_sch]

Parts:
C4: 2.2uF; C_0603_1608Metric; Part Description 10uF 10% 10V Ceramic Capacitor X7R 0805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
C5: 0.1uF; C_0603_1608Metric; Part Description 10uF 10% 10V Ceramic Capacitor X7R 0805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
U2: M.2-keyM; M.2 - M - Amphenol - 10131758-001RLF

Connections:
/+3.3v: C4.1, C5.1, U2.2 (3.3V), U2.4 (3.3V), U2.12 (3.3V), U2.14 (3.3V), U2.16 (3.3V), U2.18 (3.3V), U2.70 (3.3V), U2.72 (3.3V), U2.74 (3.3V); also elsewhere on the board
/PCIE_CLK_N: U2.53 (REFCLKn); also elsewhere on the board
/PCIE_CLK_P: U2.55 (REFCLKp); also elsewhere on the board
/PCIE_CLK_nREQ: U2.52 (CLKREQ#); also elsewhere on the board
/PCIE_RX_N: U2.41 (PERn0/SATA-B+); also elsewhere on the board
/PCIE_RX_P: U2.43 (PERp0/SATA-B-); also elsewhere on the board
/PCIE_TX_N: U2.47 (PETn0/SATA-A-); also elsewhere on the board
/PCIE_TX_P: U2.49 (PETp0/SATA-A+); also elsewhere on the board
/PCIE_nRST: U2.50 (PERST#); also elsewhere on the board
GND: C4.2, C5.2, U2.1 (GND), U2.3 (GND), U2.9 (GND), U2.15 (GND), U2.21 (GND), U2.27 (GND), U2.33 (GND), U2.39 (GND), U2.45 (GND), U2.51 (GND), U2.57 (GND), U2.71 (GND), U2.73 (GND), U2.75 (GND); also elsewhere on the board

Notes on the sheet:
M.2 NVME drives take ~ 8W @ 3.3V
not using wake pin


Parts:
C6: 47 uF / 6.3V; CP_EIA-2012-15_AVX-P
C7: 10 uF / 25V; C_0603_1608Metric
R9: R; R_0603_1608Metric
U3: MYLSM00502ERPL

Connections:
/+3.3v: C6.1, U3.7 (VOUT); also elsewhere on the board
/+5v: C7.1, U3.4 (VIN), U3.5 (EN); also elsewhere on the board
GND: C6.2, C7.2, R9.2, U3.2 (GND), U3.3 (GND), U3.6 (GND), U3.8 (GND), U3.9 (GND); also elsewhere on the board
unnamed: R9.1, U3.1 (VAR)


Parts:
C1: 10u; C_0603_1608Metric; Part Description 10uF 10% 10V Ceramic Capacitor X7R 0805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
C2: 2.2uF; C_0603_1608Metric; Part Description 10uF 10% 10V Ceramic Capacitor X7R 0805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
C3: 0.1uF; C_0603_1608Metric; Part Description 10uF 10% 10V Ceramic Capacitor X7R 0805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
J3: Micro_SD_Card_Det; amphenol-sd-push-pull_114-00841-68; Part Description 9 (8 + 1) Position Card Connector micro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
R5, R6: nf; R_0603_1608Metric; Part Description Resistor 1K M1005 1% 63mW
R7: 12K 1%; R_0603_1608Metric; Part Description Resistor 12K M1005 1% 63mW
U1: RT9742GGJ5; SOT-23-5; Part Description Power Switch/Driver 1:1 N-Channel 1A TS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

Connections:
/+3.3v: C2.1, C3.1, R5.1, R7.1, U1.5 (IN); also elsewhere on the board
/SD_CLK: J3.5 (CLK); also elsewhere on the board
/SD_CMD: J3.3 (CMD); also elsewhere on the board
/SD_DAT0: J3.7 (DAT0); also elsewhere on the board
/SD_DAT1: J3.8 (DAT1); also elsewhere on the board
/SD_DAT2: J3.1 (DAT2); also elsewhere on the board
/SD_DAT3: J3.2 (DAT3/CD); also elsewhere on the board
/SD_PWR_ON: R7.2, U1.4 (EN); also elsewhere on the board
/sd/Reserved: R6.1
/sd/SD_PWR: C1.1, J3.4 (VDD), U1.1 (OUT)
GND: C1.2, C2.2, C3.2, J3.6 (VSS), J3.11 (SHIELD), U1.2 (GND); also elsewhere on the board
unnamed: J3.9 (DET_B), R6.2
unnamed: J3.10 (DET_A), R5.2

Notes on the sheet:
CM4Lite SDCARD I/F


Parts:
C8: 2.2uF; C_0603_1608Metric; Part Description 10uF 10% 10V Ceramic Capacitor X7R 0805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
C9: 0.1uF; C_0603_1608Metric; Part Description 10uF 10% 10V Ceramic Capacitor X7R 0805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
U4: FSUSB42MX; UQFN-10_1.6x2.1mm_P0.5mm

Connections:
/+3.3v: C8.1, C9.1, U4.1 (VCC); also elsewhere on the board
/USB2_DEV_N: U4.6 (HSD0_M); also elsewhere on the board
/USB2_DEV_P: U4.7 (HSD0_P); also elsewhere on the board
/USB2_HOST_N: U4.8 (HSD1_M); also elsewhere on the board
/USB2_HOST_P: U4.9 (HSD1_P); also elsewhere on the board
/USB2_N: U4.4 (D_N); also elsewhere on the board
/USB2_P: U4.3 (D_P); also elsewhere on the board
/USBOTG_ID: U4.2 (SEL); also elsewhere on the board
GND: C8.2, C9.2, U4.5 (GND), U4.10 (nOE); also elsewhere on the board

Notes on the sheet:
the usb-c port can be used as an otg "device" port. this option must be selected by the user and is exclusive of "host" functions on the A port this is the intended method of flashing firmware onto the cm4
USB2_DEV should go to the type-c port
USB2_HOST should go to type-A port

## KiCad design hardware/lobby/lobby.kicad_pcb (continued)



Board: 4 copper layers, 85.0 x 56.0 mm, 40 parts (34 on the bottom side), 93 nets.

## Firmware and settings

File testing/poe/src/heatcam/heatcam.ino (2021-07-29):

#include <Wire.h>
#include <SparkFun_GridEYE_Arduino_Library.h>

#define WIRE_PORT Wire
#define SERIAL_PORT Serial
#define BAUD_RATE 115200
GridEYE grideye;

long start_ms = 0;

void setup() {
  WIRE_PORT.begin();
  grideye.begin(DEFAULT_ADDRESS, WIRE_PORT);
  SERIAL_PORT.begin(BAUD_RATE);

  SERIAL_PORT.println("waiting to start test.\nsend any ccharacter to begin\n");
  while(!SERIAL_PORT.available()){
  }

  start_ms = millis();
}

void loop() {

  long elapsed = millis() - start_ms;

  SERIAL_PORT.print("{\"elapsed_ms\": ");
  SERIAL_PORT.print(elapsed);
  SERIAL_PORT.print(", \"pixels\": [");

  for(uint8_t i = 0; i < 64; i++){
    SERIAL_PORT.print(grideye.getPixelTemperature(i));
    if(i != 63){
      SERIAL_PORT.print(",");
    }
  }

  SERIAL_PORT.print("]}\n");
}

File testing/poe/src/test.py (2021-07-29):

#!/usr/bin/env python3

import time
import json
import argparse
import math
from collections import namedtuple
import os
from korad import kel103

CONSECUTIVE_SAMPLE_FAILURE_LIMIT = 5

def main(args):

  # load configuration
  with open(args.config, 'r') as f:
    config_dict = json.loads(f.read())
  
  # convert config to tuple
  cfgtuple = namedtuple('config', config_dict)
  config = cfgtuple(**config_dict)
  
  # connect to device
  kel = kel103.kel103(args.local, args.remote, 18190)
  kel.checkDevice()
  kel.setOutput(False)

  # apply test configuration
  if config.mode == 'power':
    kel.setPower(config.value)
  elif config.mode == 'voltage':
    kel.setVolt(config.value)
  elif config.mode == 'current':
    kel.setCurrent(config.value)
  else:
    raise Exception('unknown test mode: ', config.mode)
  
  # generate logfile
  START_TIME = time.time()
  LOGFILE = os.path.join(args.outdir, config.name + '-' + str(math.floor(START_TIME)) + '.json')
  
  def log(entry, total_entries):
    if not len(entry):
      raise Exception('zero length entry!')

    with open(LOGFILE, 'br+') as f:
      f.seek( -7, 2) # _whence == 2 to indicate seeking from end of file
      
      if total_entries != 0:
        f.write(b',')
      f.write(b'\n    ')
      
      # write entry (nonzero len already ensured)
      f.write(entry)

      # write the new end of the file
      f.write(b'\n  ]\n}\n')

  def get_elapsed_seconds():
    return time.time() - START_TIME

  def get_sample():
    return {
      'headers': ('elapsed time', 'current', 'voltage', 'power'),
      'units': ('s', 'A', 'V', 'W'),
      'values': (get_elapsed_seconds(), kel.measureCurrent(), kel.measureVolt(), kel.measurePower()),
    }

  # initialize contents
  sample = get_sample()
  del sample['values']
  metadata = {
    'config': config_dict,
    'format': sample,
  }
  initial_content = {
    'meta': metadata,
    'entries': []
  }

  # prepare logfile
  with open(LOGFILE, 'bw') as f:
    f.write(bytearray(json.dumps(initial_content, indent=2), 'utf-8'))
    f.seek( -3 ,2)
    f.write(b'\n  ]\n}\n')

  # run the test
  stop_reason = None
  delay = 1/config.rate # seconds
  count = 0
  consecutive_sample_failures = 0
  kel.setOutput(True)
  while True:
    try:

      # get a sample retrying immediately on failure up to consecutive limit
      while True:
        try:
          sample = get_sample()
          break
        except Exception as e:
          print(e)
          consecutive_sample_failures += 1
          if consecutive_sample_failures >  CONSECUTIVE_SAMPLE_FAILURE_LIMIT:
            raise Exception('Too many consecutive sample failures')

      log(bytearray(json.dumps(sample['values']), 'utf-8'), count)
      count += 1
      time.sleep(delay)
      consecutive_sample_failures = 0

    except KeyboardInterrupt:
      print('stopping test')
      break
    
    except Exception as e:
      stop_reason = e
      break

  print('shutting down')

  kel.setOutput(False)
  kel.endComm()

  print('test stopped')

  if stop_reason is not None:
    raise stop_reason

  print('test complete')



# when run as the main script:
if __name__ == '__main__':
  parser = argparse.ArgumentParser(description='Parallel Network Ping Utility')

  parser.add_argument('-l', dest='local', required=True, help='ip address of local (your pc) ethernet/wifi interface')
  parser.add_argument('-r', dest='remote', required=True, help='ip address of device (kel103) ethernet interface on network')
  parser.add_argument('-o', dest='outdir', default='.', help='output directory for test')
  parser.add_argument('-c', dest='config', default='$\{outdir\}/config.json', help='configuration file for the test')

  args = parser.parse_args()
  main(args)

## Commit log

2021-05-04 initial commit
    this contains one schematic with pretty much all the necessary bits
    todo: break into two parts for upper and lower pcbs
    [CM4IOv5.kicad_pcb, CM4IOv5.kicad_sch, CM4_GPIO.kicad_sch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]
2021-05-04 initial commit
    planned out project structure and completed schematic for 'lobby' board
    schematic for 'mezzanine' board todo
    [CM4_HighSpeed.kicad_sch, camera.kicad_sch, escalator.kicad_sch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]
2021-05-06 start routing mezzanine
    making a progress capture before trying to cram a lot of signals onto just one hirose connector...
    [CM4IOv5.kicad_sch, CM4_GPIO.kicad_sch, CM4_HighSpeed.kicad_sch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]
2021-05-06 finished mezzanine signal routing
    [eth.kicad_sch, hdmi.kicad_sch, indication.kicad_sch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]
2021-05-13 sheet refs relative, copied escalator pinout to lobby
    [camera.kicad_sch, escalator.kicad_sch, eth.kicad_sch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]
2021-05-31 move structural hirose connector
    to match location on the lobby board
    [mezzanine.kicad_pcb]
2021-05-31 work abroad
    did some light planning for the lobby board while on vacation. now ready for final placement + routing
    [camera.kicad_sch, escalator.kicad_sch, jumpers.kicad_sch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]
2021-05-31 addtl hdmi routing
    [eth.kicad_sch, hdmi.kicad_sch, indication.kicad_sch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]
2021-05-31 place lobby components
    [escalator.kicad_sch, jumpers.kicad_sch, lobby.kicad_pcb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]
2021-06-02 attempt to route gpio
    [lobby.kicad_pcb]
2021-06-02 removed gpio from lobby to simplify routing
    [lobby.kicad_pcb, lobby.kicad_sch]
2021-06-03 finish routing on lobby
    [jumpers.kicad_sch, lobby.kicad_pcb, lobby.kicad_sch]
2021-06-03 run drc on mezzanine
    [mezzanine.kicad_pcb]
2021-06-03 update hdmi and usbc footprints for router cut
    [mezzanine.kicad_pcb]
2021-06-03 adjust USB dp tune
    [lobby.kicad_pcb]
2021-06-03 tweak lobby
    pushed traces for wifi clearance zone
    improved cm4 footprint
    improved usb-c footprint
    [lobby.kicad_pcb, lobby.kicad_sch]
2021-06-04 tweak mezzanine
    almost ready to order
    [eth.kicad_sch, hdmi.kicad_sch, indication.kicad_sch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]
2021-06-04 update lobby
    [camera.kicad_sch, escalator.kicad_sch, jumpers.kicad_sch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]
2021-06-04 update mezzanine
    [mezzanine.kicad_pcb]
2021-06-04 run cam
    [lobby-B_Cu.gbr, lobby-B_Mask.gbr, lobby-B_Paste.gbr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]
2021-06-07 clean up
    [CM4IOv5.kicad_pcb, CM4IOv5.kicad_sch, CM4_GPIO.kicad_sch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]
2021-06-15 mirror lobby mezzanine connector
    fixing a big whoops
    [escalator.kicad_sch, lobby.kicad_pcb, power.kicad_sch]
2021-06-15 modify footprints
    add paste on hdmi and usbc
    add silkscreen outline on murata dcdc supply
    change PS cap footprint to polarized footprint
    [lobby.kicad_pcb, lobby.kicad_sch, mezzanine.kicad_pcb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]
2021-06-15 update silkscreen
    [lobby.kicad_pcb, lobby.kicad_sch]
2021-06-15 cam v2
    [jumpers.kicad_sch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]
2021-07-06 change lobby hirose connectors to the DS variant
    [escalator.kicad_sch, lobby.kicad_pcb, lobby.kicad_sch]
2021-07-06 move m.2 adaptor mount hole
    [lobby.kicad_pcb]
2021-07-06 relabel switches
    [lobby.kicad_pcb]
2021-07-07 update camera connector footprint
    [camera.kicad_sch, lobby.kicad_pcb, lobby.kicad_sch]
2021-07-07 update USB-A host capacitor footprint
    [mezzanine.kicad_pcb, mezzanine.kicad_sch, usb.kicad_sch]
2021-07-07 regenerate gerbers
    [lobby-B_Cu.gbr, lobby-B_Mask.gbr, lobby-B_Paste.gbr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]
2021-07-07 satiate kicad
2021-07-10 update m.2 connector footprint
    [lobby.kicad_pcb, lobby.kicad_sch, m.2-m.kicad_sch]
2021-07-10 change fusb42mx to qfn package
    [jumpers.kicad_sch, lobby.kicad_pcb, lobby.kicad_sch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]
2021-07-10 regenerate cam
    [lobby-B_Cu.gbr, lobby-B_Mask.gbr, lobby-B_Paste.gbr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]
2021-07-10 add logo
    [lobby.kicad_pcb]
2021-07-10 regen cam data
    [lobby-B_Cu.gbr, lobby-B_Mask.gbr, lobby-B_Paste.gbr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]
2021-07-10 remove footprint silk on logo
    [lobby.kicad_pcb]
2021-07-10 regen gerbers
    [lobby-B_Cu.gbr, lobby-B_Mask.gbr, lobby-B_Paste.gbr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]
2021-07-10 hide designators in silk
    [lobby.kicad_pcb]
2021-07-11 remove reference hardware
    [CM4IOv5.kicad_pcb, CM4IOv5.kicad_sch, CM4_GPIO.kicad_sch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]
2021-07-29 add variable sample rate
2021-07-29 add heatcam srcs
2021-07-29 Update heatcam_processing.pde
    now handles json format
2021-11-29 pushing local changes
    including prelim docs
    [mezzanine.kicad_pcb]
2024-04-25 show and tell
    [mezzanine.step]
